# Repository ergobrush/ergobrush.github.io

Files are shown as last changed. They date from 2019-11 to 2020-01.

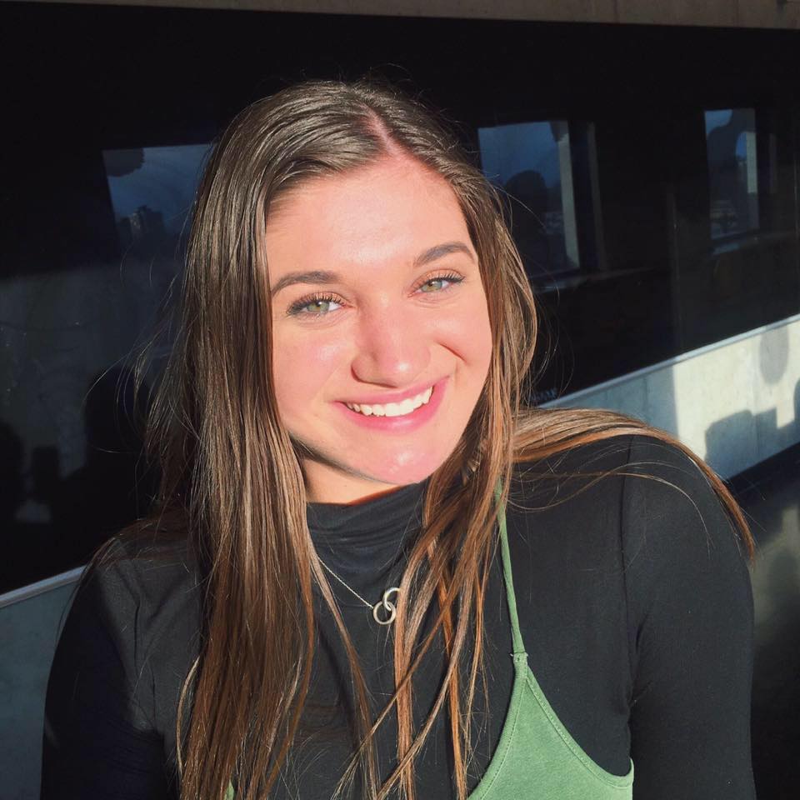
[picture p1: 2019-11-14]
img/kate.jpg

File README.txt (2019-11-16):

Ergobrush
=========

Description:
Ergobrush is a hand held gimbal-style device that provides three axis of rotation. This allows the user to achieve all desired angles to fully brush their teeth without necessitating the movement of their hand. Our device is designed to provide independence to individuals with hand mobility constraints when brushing their teeth.

Team Members:
Anbo Xu
Andre Frenette
George Abou-Hamad
Kate Ford
Lucas Hubert

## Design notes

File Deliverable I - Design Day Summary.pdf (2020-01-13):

Project Deliverable I: Design Day Pitch and Final Prototype Evaluation GNG 2101 – Intro. to Product Dev. and Mgmt. for Engineers Faculty of Engineering – University of Ottawa

Date: November 28th 2019
Group number: Group 10
Group members: Andre Fernette, Anbo Xu, George Abou-Hamad, Kate Ford, Lucas Hubert

Introduction
In preparation for this long awaited and important day, our group got together to brainstorm ideas on how we could best present our final prototype. Together, we prepared a 2 minute pitch that we would deliver to our judges, peers, professors, potential users, customers and anyone who else who may be interested in our product. We also prepared ourselves to answer any potential questions that may be asked pertaining to our design. This two minute pitch contained the information regarding the “So What?”, “Who Cares?” and “Why us?” aspects of our device and ended in a live demonstration of our fully functional prototype.

We also provided our visitors with various visuals to refer to during our presentation. This included a presentation board, our first prototype model, our final prototype and two display screens as shown below.

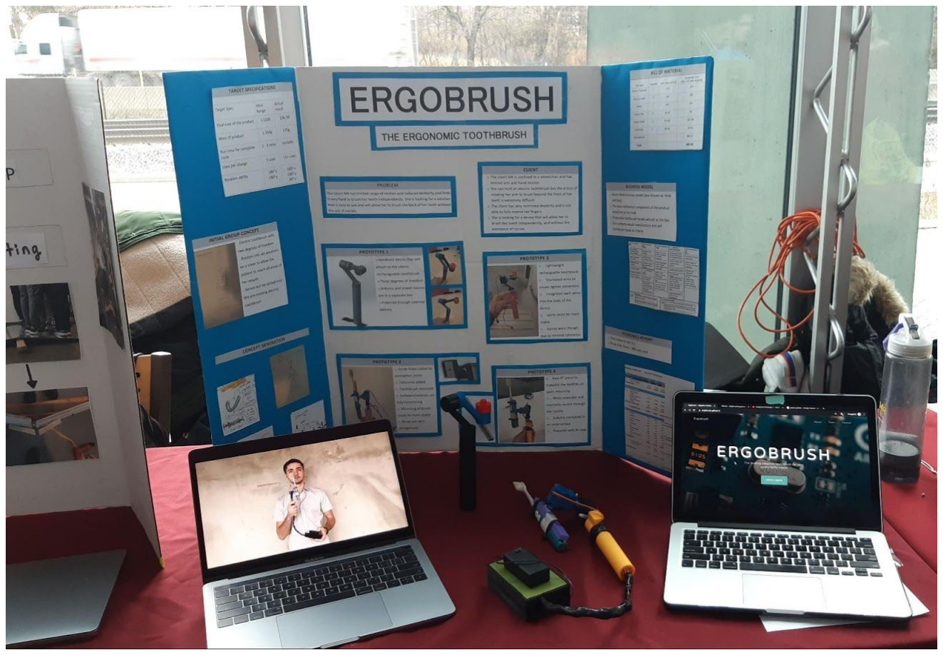
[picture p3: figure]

Design Day Presentation Material breakdown:

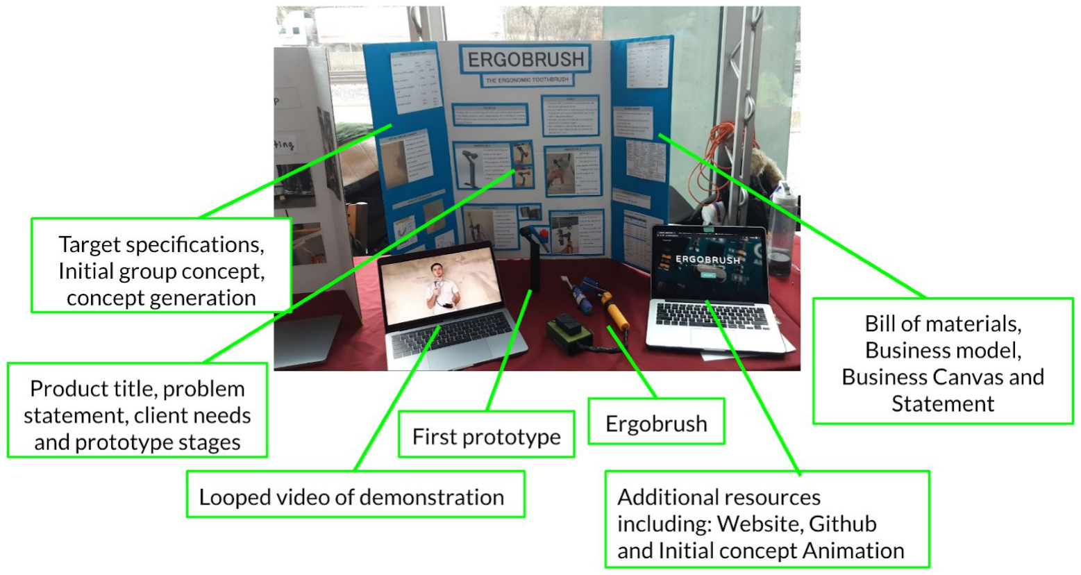
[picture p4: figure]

We used a presentation board to illustrate the design process we had followed throughout the semester. On the left we have the target specifications, initial group concept and concept generation. In the middle we have our product name, problem statement, client needs and animations and pictures of our various prototypes we designed. Finally, on the right we included the bill of materials, our business model, business canvas and a 3 year economics statement.

On the bottom left screen we have a video of one of our team members demonstrating the device in use. We uploaded this video to youtube and looped it throughout the day to provide visitors a quick glimpse of how the device functions.

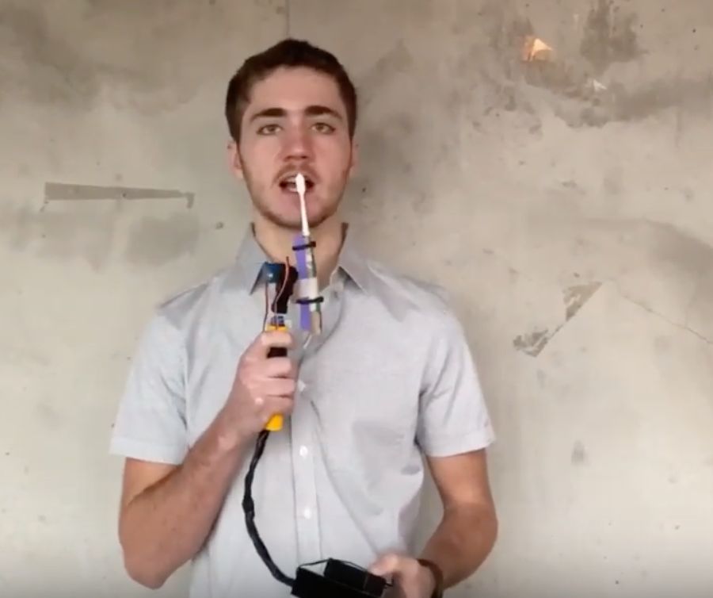
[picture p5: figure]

https://youtu.be/_NtiQT6FsqM

On the bottom right screen we provided additional resources that we believed would be of use to our judges and visitors. This included a link to our website and github page which was used to view the code implemented. We also demonstrated a short animation of our initial concept we rendered in cinema 4D.

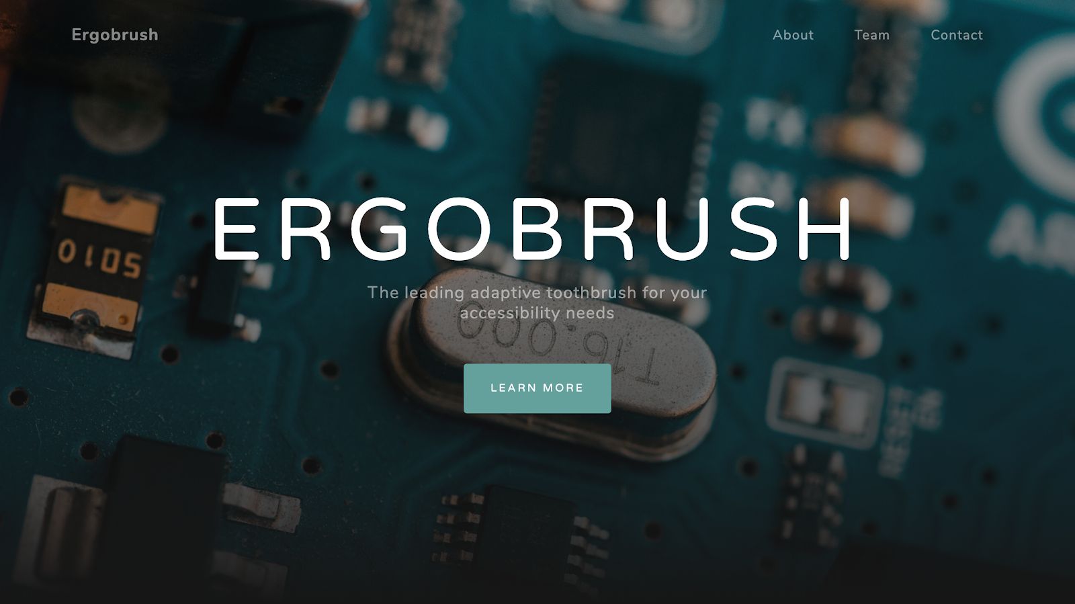
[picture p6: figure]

https://ergobrush.github.io/

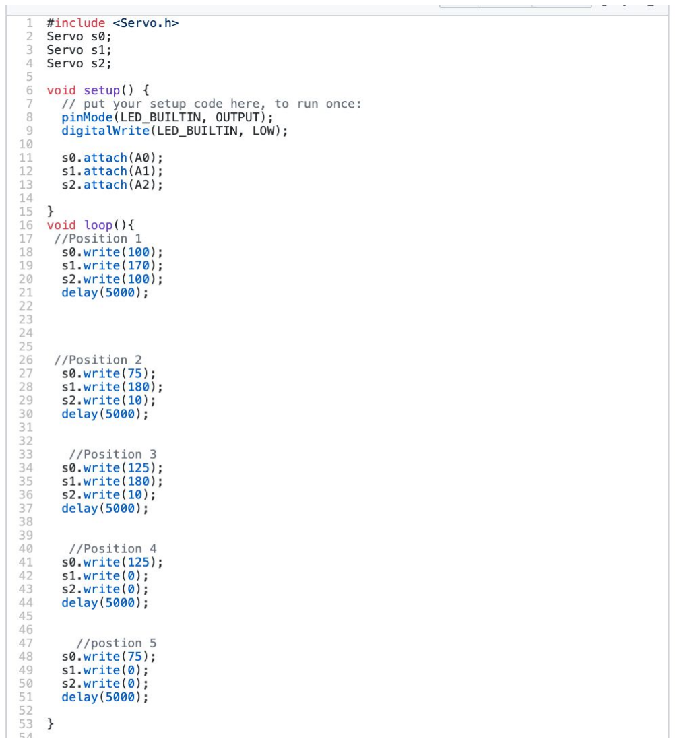
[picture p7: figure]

https://github.com/ergobrush/ergobrush.github.io

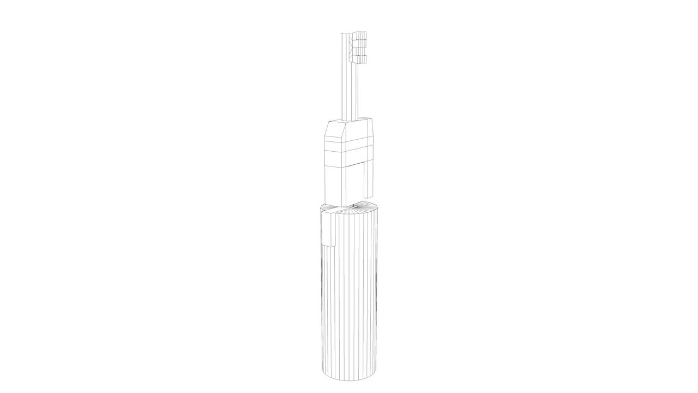
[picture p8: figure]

https://www.youtube.com/watch?v=FklP977IuZg

Two-line summary:
Ergobrush is a hand-held assistive toothbrush that allows the user to brush their teeth without requiring the need to move their hand. By offering three axis of rotation, Ergobrush effortlessly emulates a natural brushing experience through the execution of timed positioning sequences.

Conclusion
Although we did not place in the competition, we had a great time presenting the product of our hard work. We received many compliments on our design as well as good feedback and potential adjustments to better improve our product moving forward. Most importantly, as a team we believe we gained a lot in terms of technical and team working skills. From communication to group management, we will carry and apply what we’ve learned together in our future experiences to come.

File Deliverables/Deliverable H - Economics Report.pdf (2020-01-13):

Project Deliverable H: Economics Report and 1 Minute Video Pitch GNG 2101 – Intro. to Product Dev. and Mgmt. for Engineers Faculty of Engineering – University of Ottawa

Date: November 14th 2019
Group number: Group 10
Group members: Andre Fernette, Anbo Xu, George Abou-Hamad, Kate Ford, Lucas Hubert

Introduction

In this deliverable we will develop a forecasted income statement for our company based on the business model we previously developed for our team’s product. To achieve this, we will classify the various costs associated with our business, develop a 3-year income statement, determine our break-even point using an NPV analysis and finally provide arguments justifying the assumptions made in developing our economics report.

Finally, we will create a short video introducing our brand, explaining the problem we are solving and discuss the competitive advantages our solution has to offer. Our video pitch will be directed towards potential clients and investors.

H.1 Economics report:

### 1. Include a list of: variable, fixed, direct and indirect costs associated with your

business, based on the manufacturing and sale of your product. Make sure that you distinguish between price and cost and realize that prototyping and higher-volume manufacturing costs will probably differ.
Cost | Classification
Material | Variable, Direct Cost
Production | Variable, Direct Cost
Salary | Fixed, Indirect Cost
Depreciation | Variable, Direct Cost
Overhead | Fixed, Indirect Cost
Electricity | Variable, Indirect Cost

Rent | Fixed, Direct Cost
Financing | Variable, Indirect Cost
Cost of Labour | $18/hour
Material Costs | Injection molding - 1kg at $1/kg Servos - 3 servos at $10/servo Arduino - 1 arduino uno at $10/arduino Arduino Shield - 1 Shield at $5/shield External Battery - 1 battery at $5/battery
Total Material Costs | $51

### 2. Develop a 3-year income statement, which includes: sales revenue and costs of

goods sold for each year, gross profit, operating expenses and operating income (no need to include interest and taxes).

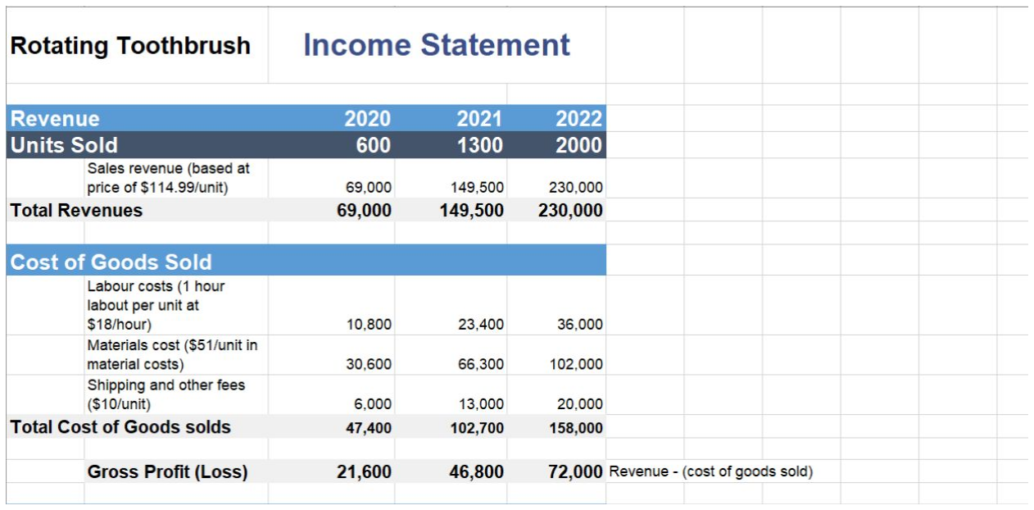
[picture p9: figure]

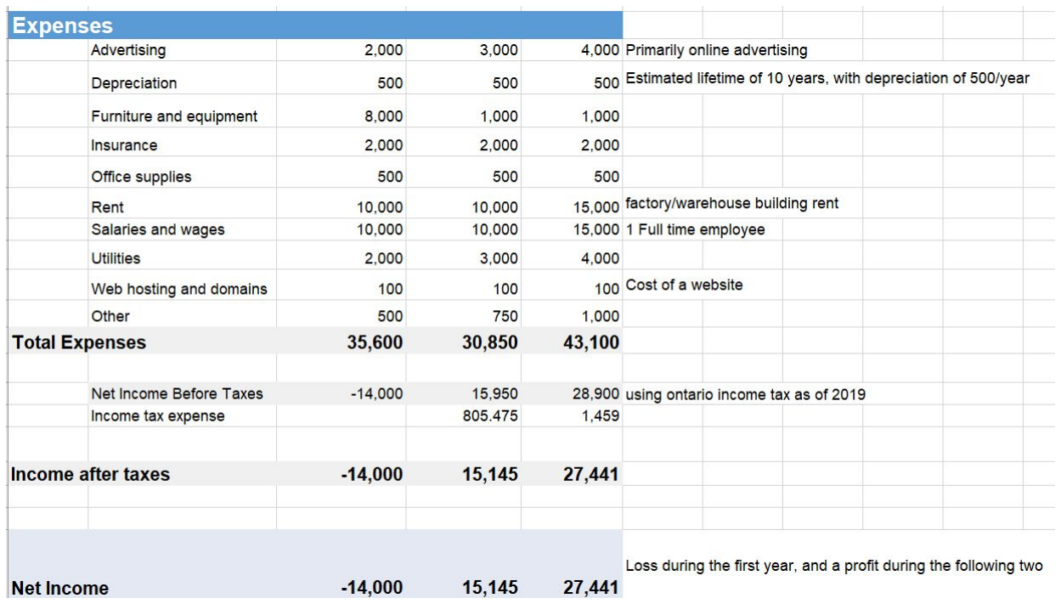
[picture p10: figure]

### 3. Using a NPV analysis, determine the break-even point (it is highly unlikely that your

operating income will be positive in the first year because of fixed costs).

Break-Even Point = (Fixed Cost) / (Sales Price Per Unit - Variable Cost Per Unit) Break-Even Point = (35,600) / (115 - 79)
Break-Even Point = 988.8 units
Break-Even Point = 989 units

### 4. Describe and justify all assumptions that you have made in developing your

economics report.

Assumption | Justification
Supply/Dema nd analysis | According to Statistics Canada, there are 60,000 people with cerebral palsy living in Canada. Assuming 1% of those people would benefit and purchase our product that is 600 people. This is where the number of unit sales in the first year originated from. Since our product is not targeted solely to people with cerebral palsy, the 600 units will consist of other various demographics sharing similar issues.
Tax | As our company will operate locally, the income tax was calculated using the

| current Ontario income tax stating that $10,582 - $43,902 has a tax of 5.05%.
Unit pricing stability | It is unlikely that the prices of our units will fluctuate as the raw materials used are relatively inexpensive and abundant in the market. As our wages are set significantly above the average minimum wage in Canada, it is also unlikely that we would have to wages.
Product market | The market for this product exists as it has been set with a price of $115. Upon researching our market, we noticed many other less advanced options being priced at around $100-$150. Since our targeted client demographic are individuals with disabilities, the price will most likely be covered by insurance, preventing any potential difficulties accessing our products due to financial Reasons. For those reasons we believe our product is priced fairly and competitively given its functionality.
Research and development | The product will remain current and will not require updates within the next 3 years. By keeping overall costs low, we are able to maximize our profits while also collecting data from our users. Once our company has more leeway after the first 3 years, we will analyze the feedback and if need be, design a second version of our product.

H.2 1-minute video pitch. Create a video, approximately 1 minute in length. https://makerepo.com/GeorgeA/ergobrush-the-leading-adaptive-toothbrush

Conclusion

Upon classifying our various costs associated with our business, we were able to complete our income statement. For the first three years of operation, our net income was calculated to be -$14,000, $15,145 and $27,441 respectively. We then conducted a NPV analysis, determining a break-even point of 989 units. Concluding our economics report, we analyzed and justified the various assumptions we had made in developing our economics report.

Preceding the report, we created a short video pitch with the purpose of shedding light on our problem statement while also displaying the effectiveness of our proposed solution. We decided on naming our product Ergobrush as we believe it properly encapsulates the ergonomic design and function of our device. We also created a product website which will be used to provide further information to potential clients and investors.

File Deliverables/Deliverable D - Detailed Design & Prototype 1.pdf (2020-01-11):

Project Deliverable D: Detailed Design and Prototype 1 GNG 2101 – Intro. to Product Dev. and Mgmt. for Engineers Faculty of Engineering – University of Ottawa

Date : October 3rd 2019
Group number: Group 10
Group members: Andre Fernette, Anbo Xu, George Abou-Hamad, Kate Ford, Lucas Hubert

Introduction:

MK is constrained to a wheelchair and has no hand control, as well as limited arm range. She has difficulty brushing her teeth with no assistance. Although she can hold an electric toothbrush, the action of rotating the toothbrush to reach beyond the front tooth surface is a challenge. Having a device that can assist in the rotation of the electric toothbrush will allow her to live more independently. This rotational toothbrush must use off-the-shelf brush heads for sanitary reasons. Ideally, this toothbrush is rechargeable, but a secure power wire is acceptable.

Since being assigned the task to solve MK’s problem, our team has worked long and hard in formulating a viable solution for our client. Following the directions in deliverable C, we were able to clarify the core functionalities our solution was to have. We then pooled together our ideas, further analyzing them using concepts learned in class such as the decision matrix. Using the results obtained from these matrices, we developed a group concept that integrated key components found in the most promising solutions. Finally, we developed a project plan, conducted a feasibility study and created a bill of materials and parts to verify the viability of our proposal.

Our current objective is to design details for our concept and to build our first prototype. This will serve as a means to test the product’s most critical functionality and target specifications. We will then use the prototype to interact with our client and obtain valuable feedback on our next meeting.

GNG 2101 – Intro. to Product Dev. and Mgmt. for Engineers

### 1. Summarize the client feedback that you received during your second meeting

for your conceptual design and clearly state what needs to be changed or improved in your design.

Upon meeting with our client for a second time, we were able to present our group concept we had at the time. This meeting was extremely informative as we were given feedback regarding the feasibility aspects of our concept.

At the time of our second meeting, our group concept was a customized standard electric toothbrush that would have two degrees of freedom. While being operated, the upper portion of the toothbrush would be able to spin and tilt, allowing the user to reach an increased amount of surface area without necessitating hand motion. We created the sketches below as an accurate representation of our product concept at the time.

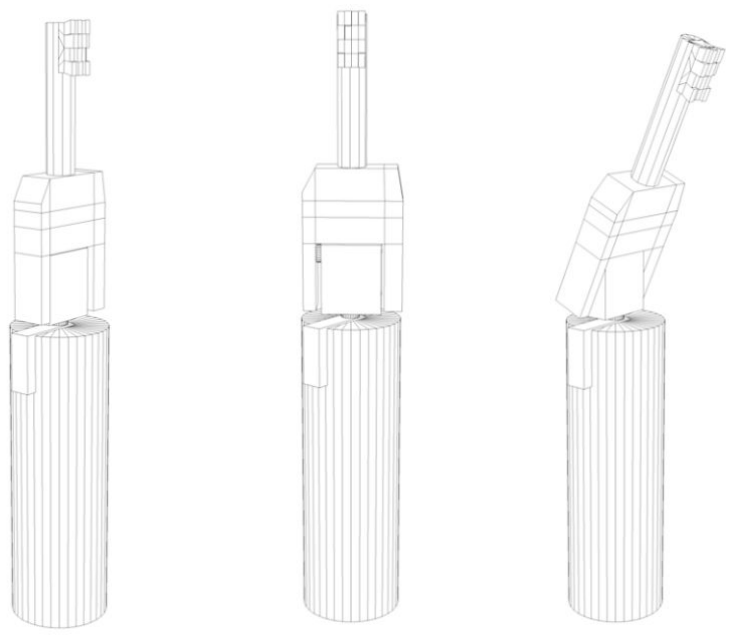
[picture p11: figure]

However innovative the concept was, the client did express some concerns with its design. The proposed device needed a continuous flow of energy from a power outlet in order to power the various electrical components while being operated. Since our product will be in contact with water, we were advised that the device must be unplugged while in use to ensure the safety of the user. To improve this design characteristic, we decided to modify our concept to contain an external battery component that the device would draw energy from and that could be recharged when not in use. This would also be of great use to house the wires, keeping them away from the chairs vicinity and to prevent potential damages to the system from contact with water.

Our client also expressed concerns with regard to the weight of our design. As the weight of our concept included a standard electric toothbrush as well as an arduino, two servos, wiring and a longer 3D printed case, the weight of the device would not meet our clients needs. In order to have a viable concept, our target specification for weight must not significantly exceed the weight of the current toothbrush she uses. We realized that an alternative concept was needed, ideally one that did not require all the components to be affixed to the toothbrush itself.

Another concern from our client was the complexity of our design. Given the course’s restricted timeline and the limited time allocated to build the final prototype, the client recommended that we keep our design as simple as possible to make sure that we are able to complete it on time. In order to achieve that, we planned on developing a simpler design to ensure that we could complete each design process milestone leading to our final prototype on time. Also, crucial steps such as software testing will have to be completed well ahead of design day to ensure that it is functioning properly and according to our target specifications.

Given the feedback provided by our client and project manager, we decided to make important changes to our design. We realized our design needed to be first and foremost safe, light weight, cost effective and simple in nature. In order to meet these specifications, the device had to work independently to the toothbrush. By choosing a design concept as such, we would dramatically decrease the cost of our product as we would simply use our clients current toothbrush. This would also maintain the integrity of the electric toothbrush and prevent any safety concerns that could arise by directly altering its components.

### 2. Develop an updated and detailed design of your concept, based on your client

meeting, which includes: Visual representations of the overall concept, as well as each subsystem. Clearly define how each subsystem is linked to other subsystems (including fasteners and electrical wires).

Through a collective effort, we were able to conceptualize a design that met our product specifications. Our new design is a hand held device that would attach to our clients toothbrush and perform various movements. The design was inspired by a phone gimbal, a hand held device that is meant to stabilize a phone while taking video. A sketch of our new design is provided below.

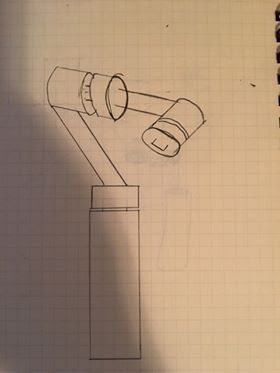
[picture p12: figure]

An updated, visual design of our overall concept created in Solidworks is provided below.

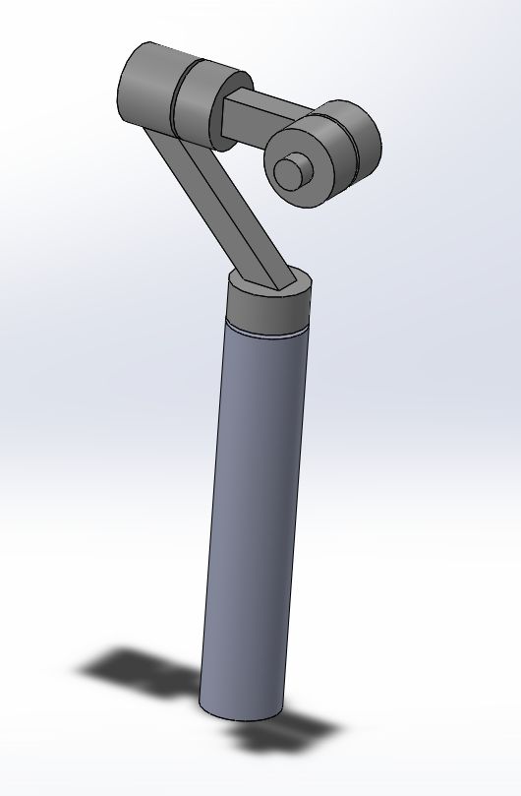
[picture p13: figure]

Subsystems at a glance: Handle, servos, wires, different pieces on the gimbal.

Our concept incorporates a simple design that would be comprised of a handle, various pivots through the use of servos and a fastener that would latch onto the toothbrush, providing the motions needed for the user to brush their teeth.

In order to guarantee full product functionality to our client, certain preconditions must be met during the external boundary phase. To begin, the toothbrush intended to be used must be picked up, wrinsed, have toothpaste applied to the bristles and the toothbrush must be attached to the device. Additionally, both the toothbrush and device must be charged to ensure proper functioning. The device must also be handed to our client and turned on as she is incapable to do so alone.

The system will now perform as advertised until our client has completely brushed all of their teeth. While holding onto the device, the toothbrush will have a timed sequence of various positions, ultimately providing the user with an ample amount of time to thoroughly brush each section of their teeth. This will be achieved using the dynamic subsystems that compose our device. These include the handle, joints/servos, battery, arduino and wires.

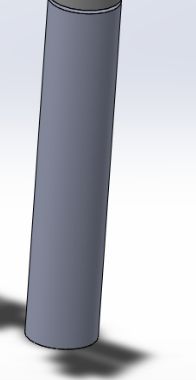
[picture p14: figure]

Handle

The handles function will serve as a replacement to the original toothbrushes handle.It will be of similar diameter to an electric toothbrush and easy to grip. Padding will be added to ensure comfort while operating device.

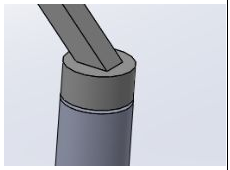
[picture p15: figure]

First Joint

The first Joint allows the device to rotate on
the xy plane. The servo will be mounted in
the handle and the second piece will be mounted onto the splines of the servo. The wires that lead to the following two servos will be routed through this joint.

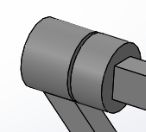
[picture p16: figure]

Second Joint | The second joint allows for the joint to have freedom of rotation on the xz plane. The joint will be assembled in the same manner as the first joint. The wires for the third servo will route through this joint in a manner that will not interfere will other motions.

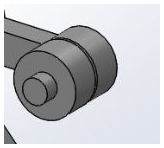
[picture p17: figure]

Third Joint | The third joint allows for freedom of movement on the xy plane. This joint will also be assembled in the same manner as 1 and 2. The third servo will allow the toothbrush to be angled away from and toward the client.
Wires | The wires are not illustrated in the visual design as they will be hidden from plain sight. They will serve as a means to connect all electrical components in order to ensure proper functioning of the device.

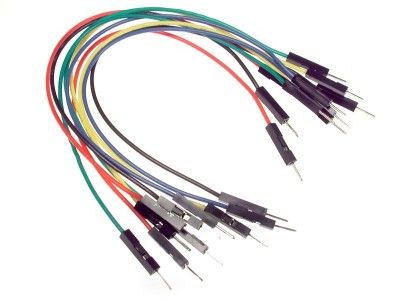
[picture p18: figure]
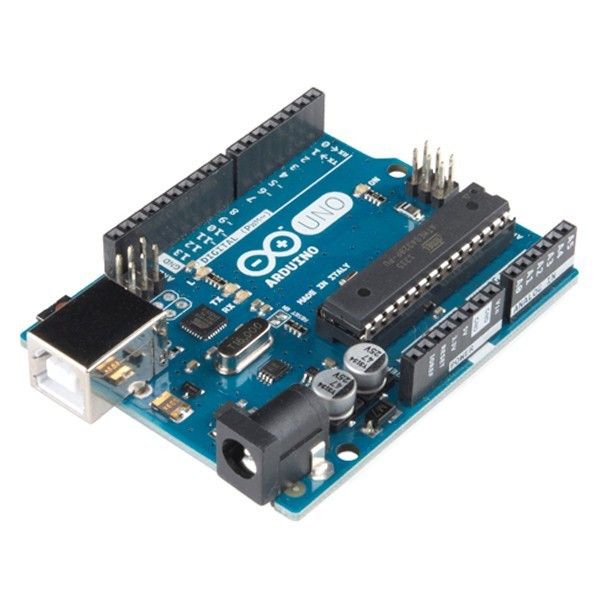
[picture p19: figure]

Arduino | The Arduino microcontroller is programmed to control the rotations of the servos. After a certain amount of time, the microcontroller will adjust the toothbrush to let the client brush other sides of her teeth. After a full cycle, the microcontroller will send signals to reorient every joint to its initial position and then automatically turn itself off.

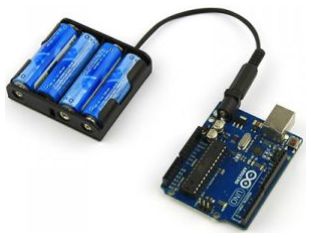
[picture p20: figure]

Battery

The battery pack we have will supply power to the arduino. We are using an external battery pack so it does not have to be plugged into a standard wall outlet. Plugging the Arduino into the wall would present an obvious safety hazard as the task of brushing your teeth involves water and having wires and power running around the client is not ideal.

Once a cycle is completed, the device will turn itself off. When the user has fully brushed their teeth, the aide will unmount the toothbrush and rinse it off. The batteries of the device and toothbrush will then need to be charged for the next use. A function will be implemented that resets the devices positioning prior to turning off.

### 3. Define your most critical product assumptions and create your first product

prototype, which will be used to test those assumptions.

In an ideal scenario, we would be able to fully test our product specifications using an unlimited amount of resources. Unfortunately, as we are advised to follow a strict budget, multiple assumptions must be made prior to developing our product. Notably, the components that tend to be the most expensive are the ones that utilize energy and perform work. These include components such as the servos, arduino and batteries.

The servos are expected to perform enough work to rotate a designated area of the device, we must assume that they will perform as intended. The device must also accomplish a sufficient amount of degrees of freedom in order to work as advertised.

To add, we must assume that our product in its entirety will share a similar weight to a standard electric toothbrush. Having it be too heavy will hinder our clients ability in utilizing it, rendering the device useless. Also, if certain areas are of too much weight, this will once again prevent our servos from completing their rotations and may potentially damage the equipment.

Taking these product assumptions into consideration, we are ready to create our first product prototype which will be used to test our assumptions.

### 4. Document your prototype using as many sketches/diagrams/pictures as

required and explain the purpose and function of your prototype.

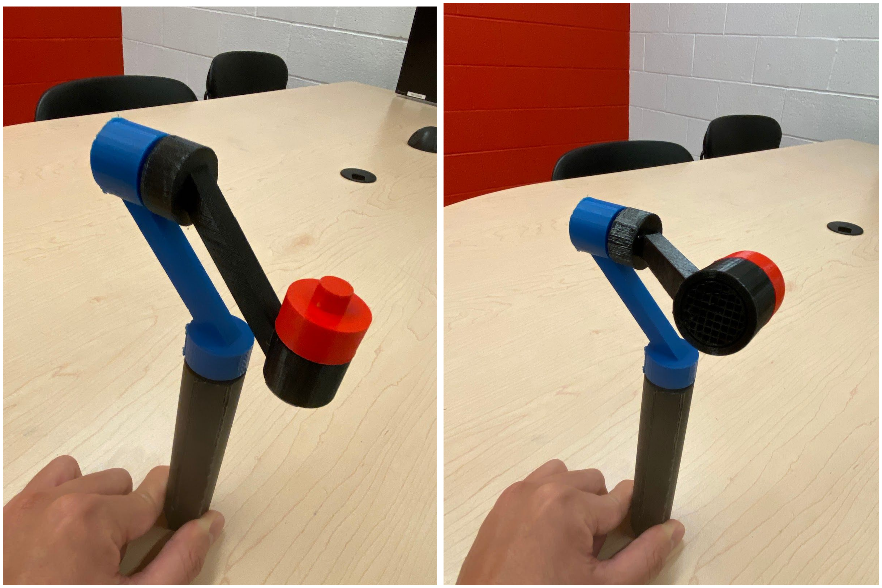
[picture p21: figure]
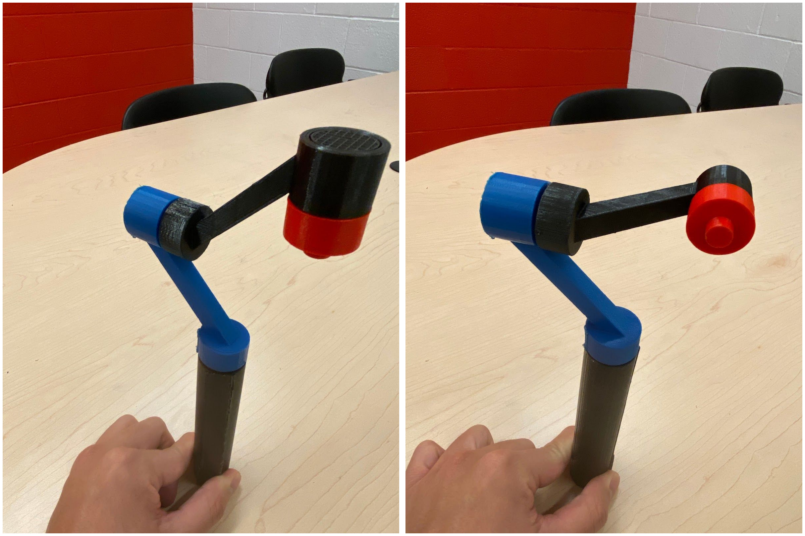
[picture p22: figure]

We created a low fidelity prototype to quickly test our idea with no cost to the team. Each of the four fidelity factors have been addressed within the initial prototype.

Functional Fidelity: This is a moderately functioning prototype. Since all the pieces were printed independently they are able to be assembled and manipulated to simulate the movement that will be happening with the servos. There is no software within the prototype so all of the movement is done manually by the user.

Visual Fidelity: This prototype is not an accurate representation of what the finished product would look like visually. The structure and shape of the product will be similar but the colors and coordination of the product will be improved.

Content Fidelity: Currently there are no placeholders for the servos what will be added to the final product. A servo will be placed at each of the three joints where the parts meet.

Depth and Breadth: The overall completeness is very surface level. From now until the final prototype there will be mechanical aspects added, a battery system will be implemented, servos will be incorporated, and a clasp to hold the toothbrush will be added as well.

The main purpose of prototype 1 was communication, specifically the validation of our ideas. Creating the prototype as a 3D printed model that we can manipulate allowed us to confirm that gimbal style will be functional and allow the client to reach all the areas of her mouth with ease. The model also let us get a feel for the weight of the product. Since the client is not able to hold something that is too heavy or off balance we are able to keep the weight in mind when building on the design.

### 5. Carry out prototype testing, analyze and evaluate performance compared to the

target specifications developed in Project Deliverable B and document all your testing results. Present your testing in an organized, tabular format that shows expected versus actual results.

As our concept was recently developed due to the feedback provided in our
second client meeting, we decided to follow the preliminary steps completed for
our older designs found in Deliverable C prior to creating our first prototype. We created a decision matrix for our gimbal design to identify, analyze, and rate each design criteria in relation to the selection criteria. The values for our matrix are set to 1 being not ideal and 5 being ideal.
Selection Criteria | Gimbal Design
Ease of Use | 5
Size & Weight | 4
# of Adjustments per cycle | 5

Safety | 4
Durability | 4
Cost Estimate | 5
Is it Realistic | 4
Total | 20

As the purpose of creating a prototype is to reduce uncertainty, we wanted to create one that would provide insight on our final product. The purpose of our prototype was to test basic functionalities of our device. Notably, we wanted a physical model that would shed light on the dimensions, weight and ergonomics of the device. We decided the optimal way in testing our product specifications was to 3D print our design as it could demonstrate the basic motions, shape and weight of our final device.

For our product size, we decided it would be best if the handle component to emulate the dimensions of a standard electric toothbrush, being 11 x 5 x 24.1 cm. We also wanted to demonstrate that the weight of our final product was expected to be relatively light. Thus, we made sure to keep the handle hollow and made sure that all components did not weigh more than an electric toothbrush ~331g. By using a simple design made of plastic for our first prototype, we were able to conceptualize where the servos would be inserted and how they would behave with respect to motion.

The portion of our functional decomposition that could be tested using our prototype were the steps included within our system boundaries. Once the toothbrush is on, attached to the extremity and given to the user, we would then illustrate the different positions the toothbrush could achieve without the movement of the users hand.

The assembly of the prototype was relatively easy, though not completely stable. It did suffice to give the user a general idea as to how the form of the final concept would be like. We then provided our prototype to our friends to receive user feedback. Overall the feedback was positive. The metrics of what was tested, expected results and actual results are provided in the table below.

Test | Expected | Actual
Length when standing up with the red component | 20cm | 23cm

shown in the picture facing down | Size of the apparatus is similar to an electric toothbrush. | Size of handle and feel were accurate. Upper components were slightly big and could be a problem when oriented too close to the users face.
Weight | 200g Product is lightweight, similar to that of an electric toothbrush. | 164g Weight was very similar to an electric toothbrush. Though the prototype did not contain any of the components we plan on adding, the fact that it was significantly lighter provides good prospects of a light final product, for when we do decide to add them.
Ergonomics | Prototype demonstrates efficiency and is easy to use. Provides a comfortable and natural feeling, similar to holding a toothbrush. | Emulated with significant accuracy the feel and design of an electric toothbrush. Upper components were slightly big and could be a problem when oriented too close to the users face.

Overall the feedback was positive. Some confusion arose as to how the device was to behave when on. Recommendations on timed intervals as opposed to buttons for the various different motions were asked. To get accurate feedback regarding our client, when we informed our testers on the physical constraints of our client, the majority of our testers preferred a timed design.

Testing our prototype was an inexpensive and time saving process that provided important insight on the direction we should follow from here on out.

### 6. Outline what your team intends to present to your client(s) and what

information you would like to gather at your next client meeting.

Much has changed since our second client meeting. As a team, we have decided upon a completely different product design due to the concerns and criticism provided by our client and project manager. Given the fact that our next client meeting is scheduled in roughly three weeks, we plan on taking advantage of this opportunity to further refine our current product design prior to the meeting. Based on our current expected milestones, we plan on providing our client with a high fidelity prototype by October 23rd. This comprehensive prototype will implement many of the attributes our final product will contain and be of great use for rigorous testing. This will also provide our client with a better sense of the solution, the expected features and functionalities of the final product, the option to test our prototype and ultimately give insight on preferences they may have, allowing us to further refine and finalize decisions pertaining to our final product.

By inquiring on our clients personal preferences, taking into account their exact movement capabilities, we are given the opportunity to further meet their needs by altering the specific timing and positioning preferences they may have with respect to the motion of the device. We will achieve this by modifying the code affecting the functionality of our servos. This is now a possibility due to our newly acquired knowledge upon completing our most recent laboratory. During this lab, we utilized the Arduino IDE Software platform to write control logic commands used to create inputs and outputs connected to an Arduino Uno microcontroller.

Conclusion:

This week, we decided to develop a completely new design influenced by the feedback provided during our second client meeting. We then created our first prototype using the designed details of our concept through the use of sketches and 3D models. We tested our products most critical functionalities and target specifications with friends to get informative criticism on our product design. Finally, we established what we plan on presenting in our next client meeting as well as inquire on preferences that will be used to finalize our product.

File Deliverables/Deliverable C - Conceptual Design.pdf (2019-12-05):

## GNG 2101 – Intro. to Product Dev. and Mgmt. for Engineers

Project Deliverable C-1: Conceptual Design
Faculty of Engineering – University of Ottawa

Date : September 26th 2019
Group number: Group 10
Submitted by: Andre Frenette, Anbo Xu, George Abou-Hamad, Kate Ford, Lucas Hubert

Introduction:

The objective of this deliverable is to develop a conceptual design for our product as well as to create a plan for completing multiple prototypes in time for Design Day. In order to verify the viability of our proposed concepts, we conducted a feasibility study and created a bill of materials and parts (BOM).

### 1. Based on customer needs, clarify core functionality by breaking down required

product functions (functional decomposition) into smaller basic sub-functions, identifying external sub-system boundaries.

Functional Decomposition:

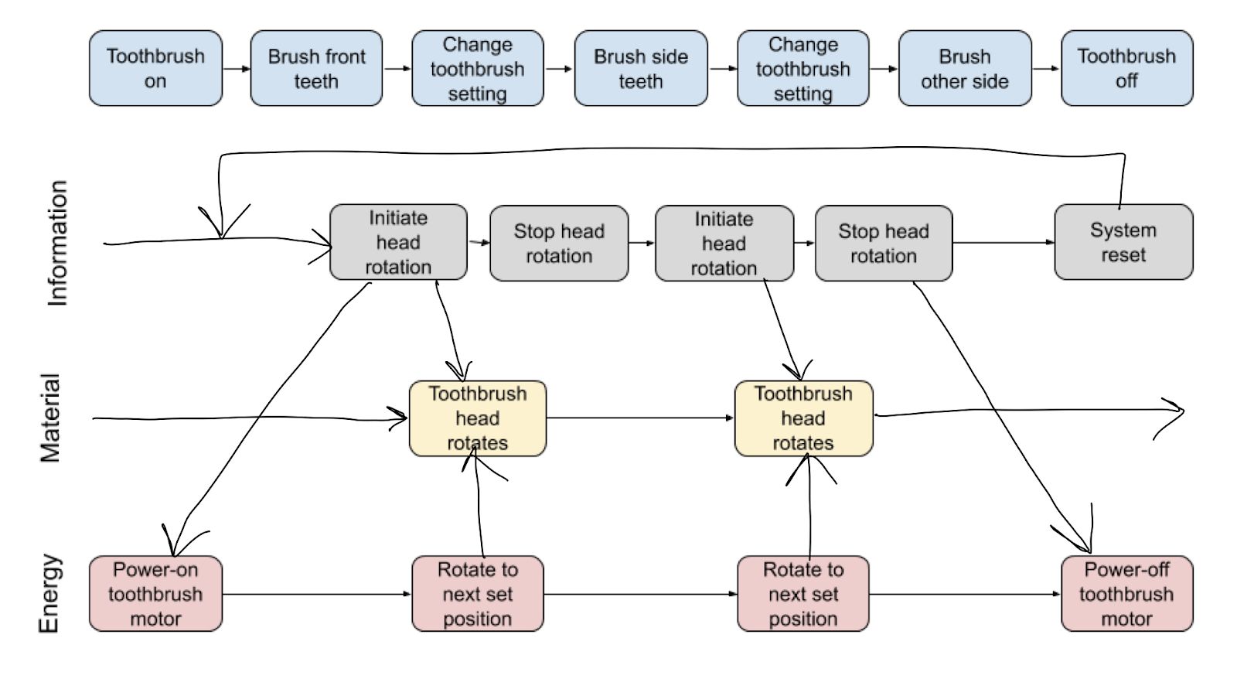
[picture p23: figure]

### 2. Provide a minimum of 3 product concepts per team member (clearly identify

each concept’s creator).

Lucas’ concepts:

1) A device that attaches around the head while the toothbrush is inserted in the mouth. The functionality of the device will rely on the user's head movement. As our client would prefer a solution that aides, but does not replace her participation in brushing her teeth, a design such as this could incorporate our clients strengths while minimizing the necessity of their weaknesses. Potential cons for this solution would be the complexity in the setup stage, the size of the apparatus as well as its increased weight.

Pros: Relies on the client’s strengths to operate the toothbrush. Requires minimal hand movement.

Cons: It would be hard to set up, and take up a lot of space. Also, depending on the materials used, weight could be an issue.

2) A longer toothbrush that has a better reach than a standard one could be a viable solution. By utilizing such a device, reaching the teeth located on the side and back regions of the mouth could be achieved without moving the users hand. Adding length to the toothbrush would inevitably increase the weight of the device which could be an issue. An increased difficulty in handling the toothbrush may also arise given the change in the devices overall form.

Pros: It would make it easier to reach the sides and back of the mouth cavities without having to move hands. This would allow the client to only rely on head movement, one of her strengths.

Cons: Weight could be an issue. Also, it could be hard to grab or use given the client’s restricted hand motion.

3) Device to wrap around hand to make grabbing the toothbrush. Adding optional extra length to allow to use head movement to reach sides and back of mouth cavity. A device that would assist the user by wrapping around their hand could be of potential use to our client. It would be an inexpensive tool in providing extra grip to the toothbrush while it is being operated. The attachment and removal procedure as well as the additional weight on the users hand could be an issue.

Pros: Easy to use, it would provide extra grip to help the client grab and use the toothbrush.

Cons: Again, weight could be an issue, as well as set up. If it is too heavy, it could be problematic given the client’s limited hand strength.

George’s concepts:

1) A 3D printed piece that would attach between the base of the electrical toothbrush and the removable head. This piece would be comprised of 2-3 compartments, one being a cog. The cog would have around 4 protrusions that would be used as a gripping tool to turn the head piece. It would be designed to turn clockwise in 90 degree increments with the use of applied force. For instance, once the user has completed the task of brushing their front teeth, they would then bite on the cog and twist using both their arm and head. Upon completion, the bristles would be facing 90 degrees away from its initial position and the user may now begin brushing the surface of their bottom teeth.

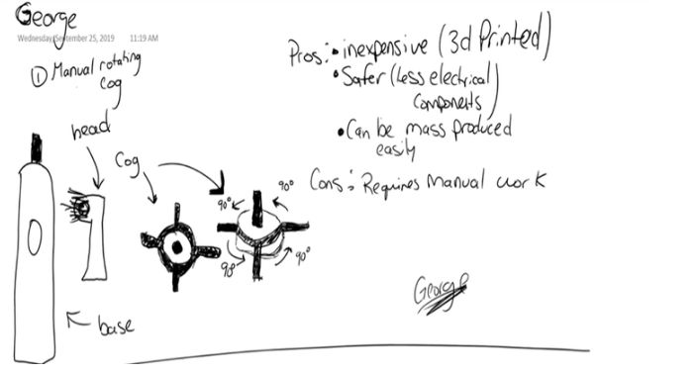
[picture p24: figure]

2) An attachable handle that would rotate via a control. The Handle would attach to the chairs surface or bathroom sink and grip the toothbrush when being operated. An easy to use button that would require minimal pressure would be in the users reach. When the button is pressed, the rotational mechanism would be

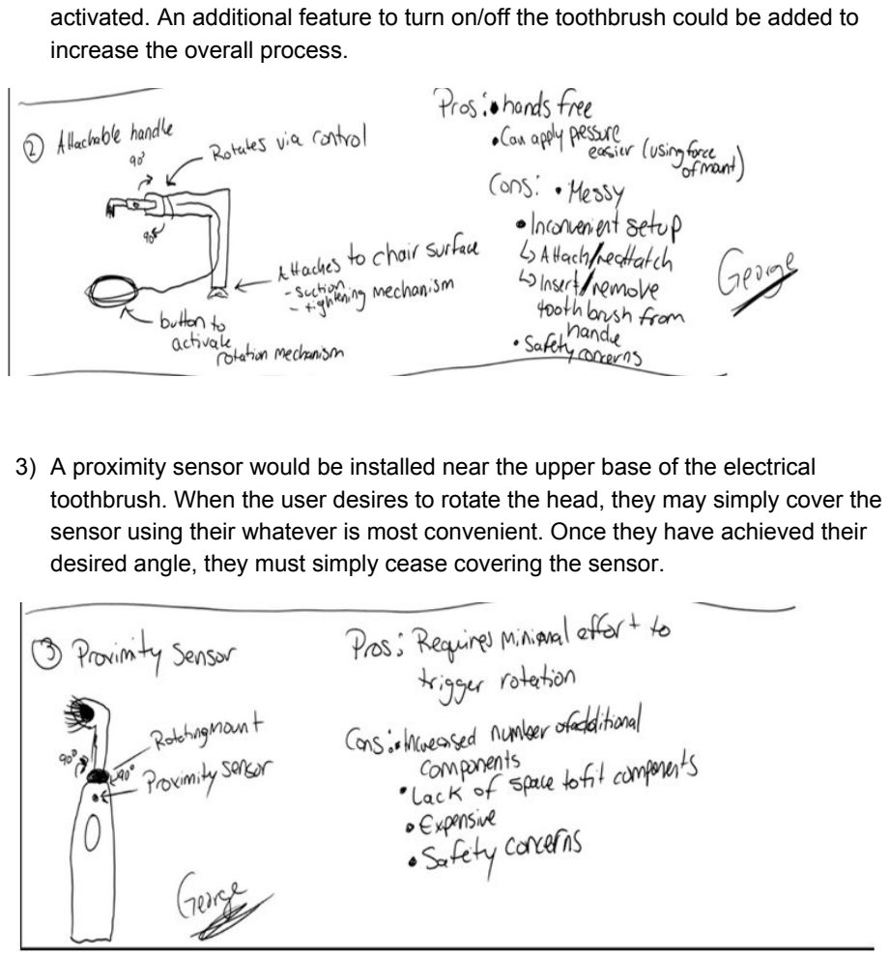
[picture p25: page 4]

activated. An additional feature to turn on/off the toothbrush could be added to increase the overall process.

3) A proximity sensor would be installed near the upper base of the electrical toothbrush. When the user desires to rotate the head, they may simply cover the sensor using their whatever is most convenient. Once they have achieved their desired angle, they must simply cease covering the sensor.

Anbo’s Concepts:

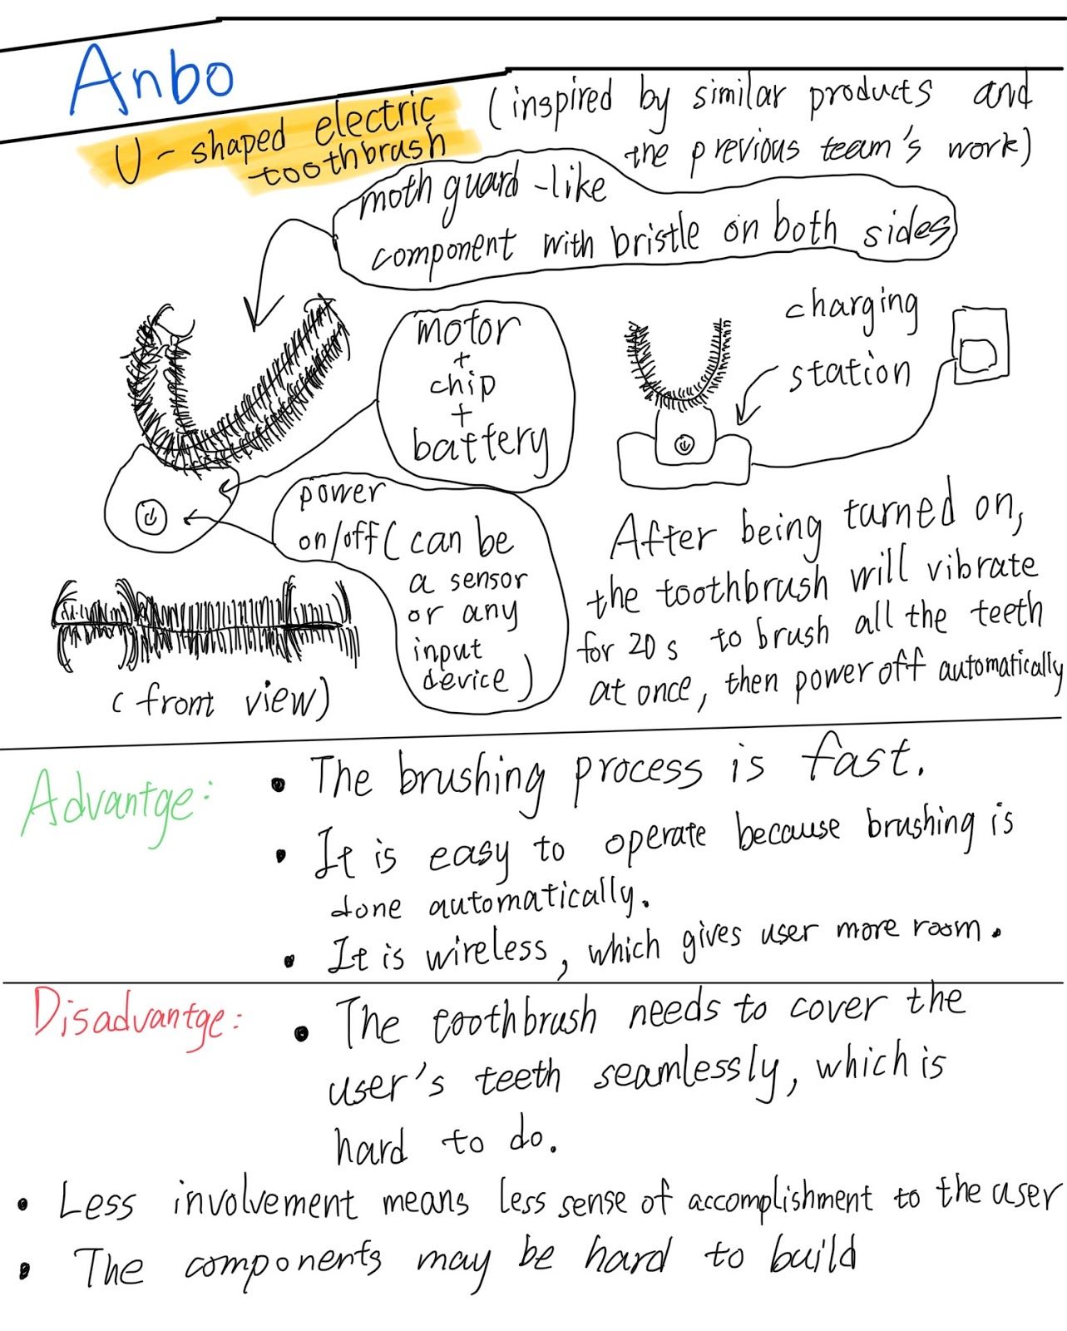
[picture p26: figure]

Kate’s Concepts:


Andre’s Concepts:


### 3. Analyze and evaluate all concepts provided by each team member based on

the target specifications of Project Deliverable B. Use simple calculations and/or simulations to make decisions. Justify the process and methods used for analysis and evaluation.

Upon reviewing Mana’s comments for Deliverable B, we have refined our metrics and target specifications for our solution. In order to best analyze and evaluate all concepts provided by each team member, we created a decision matrix. By doing so, we are able to systematically identify, analyze, and rate each design criteria in relation to the selection criteria. The values for our matrix are set to 1 being not ideal and 5 being ideal.

Lucas’ Concepts
Selection Criteria | Concept 1 | Concept 2 | Concept 3
Ease of Use | 3 | 3 | 4
Size & Weight | 1 | 2 | 2
# of Adjustments per cycle | 2 | 4 | 1

Safety | 3 | 4 | 4
Durability | 4 | 3 | 4
Cost Estimate | 4 | 4 | 3
Is it Realistic | 3 | 3 | 3
Total | 20 | 23 | 21

George’s Concepts
Selection Criteria | Concept 1 | Concept 2 | Concept 3
Ease of Use | 3 | 4 | 2
Size & Weight | 5 | 1 | 1
# of Adjustments per cycle | 3 | 2 | 3

Safety | 3 | 2 | 2
Durability | 3 | 2 | 2
Cost Estimate | 5 | 2 | 2
Is it Realistic | 4 | 3 | 2
Total | 26 | 16 | 14

Anbo’s Concepts
Selection Criteria | Concept 1 | Concept 2 | Concept 3
Ease of Use | 4 | 3 | 3
Size & Weight | 3.5 | 3 | 3
# of Adjustments per cycle | 4 | 3 | 3

Safety | 3 | 3 | 3
Durability | 3 | 3 | 3
Cost Estimate | 2.5 | 3.5 | 4
Is it Realistic | 4 | 3.5 | 3
Total | 24 | 22 | 22

Kate’s Concepts
Selection Criteria | Concept 1 | Concept 2 | Concept 3
Ease of Use | 4 | 3 | 2
Size & Weight | 3.5 | 4 | 3
# of Adjustments per cycle | 4 | 2.5 | 3

Safety | 3 | 3 | 3

Durability | 3 | 3.5 | 3
Cost Estimate | 3 | 3 | 2
Is it Realistic | 3 | 3 | 2
Total | 23.5 | 22 | 18

Andre’s Concepts
Selection Criteria | Concept 1 | Concept 2 | Concept 3
Ease of Use | 5 | 4.5 | 2
Size & Weight | 2.5 | 4 | 4.5
# of Adjustments per cycle | 4 | 5 | 4

Safety | 3 | 2 | 3
Durability | 2.5 | 4 | 4
Cost Estimate | 2.5 | 3 | 4
Is it Realistic | 3.5 | 3 | 3
Total | 23 | 25.5 | 24.5

### 4. Choose one or a few promising solutions you wish to develop further based on

your evaluation.

After analyzing each concept provided by our team, we have chosen 5 of the best performing concepts to further analyze . Using the same values found in question 3, we created a new decision matrix only containing our highest scoring ideas.

Selection Criteria | Option 1 Anbo’s Design #1 | Option 2 Andre’s Design #3 | Option 3 Kate’s Design #1 | Option 4 George’s Design #1 | Option 5 Lucas’s Design #2
Ease of Use | 4 | 4 | 4 | 3 | 3
Size & Weight | 3.5 | 3.5 | 3.5 | 5 | 2
# of Adjustment s per cycle | 4 | 4 | 4 | 3 | 4

Safety | 3 | 4 | 3 | 3 | 4
Durability | 3 | 3 | 3 | 3 | 3
Cost Estimate | 2.5 | 4 | 3 | 5 | 4
Is it Realistic | 4 | 4.5 | 3 | 4 | 3
Total | 24 | 27 | 23.5 | 26 | 23

Option 1:
The U-Shaped electric toothbrush is a promising concept. It is an innovative device with a brushing process that is fast, easy to operate and can be operated without being plugged into an outlet. Disadvantages noted were the cost, safety and durability.

Option 2:
Andre’s 3rd design is a simple yet effective way to tackle our clients’ needs. It requires only one servo which slightly increases its weight, though ranks high in safety, ease of use and cost.

Option 3:
Kate’s 1st design combines the idea of a mouthguard like toothbrush and a conventional toothbrush. I requires 4 preset positions to allow the client to reach all four quadrants of her mouth, making it user friendly and cuts down on time. The biggest disadvantage with this design would be the cost and that it would be very hard to achieve in the short time frame and constraints we were given.

Option 4:
George’s 1st design is a very inexpensive and simple way in implementing a rotational component on a standard electric toothbrush. Given its lack of features, it can be more strenuous for the user to achieve the desired angle. Constantly using one's teeth to bite and rotate the brush will result in quicker abrasion over time.

Option 5:
Lucas’ 2nd idea of a longer toothbrush is a very realistic design. The additional length would allow the client to reach the back of her mouth with ease and does not require additional servos or technical adjustments. The downfall to this is that the added weight would make it awkward and could be challenging given the clients limited dexterity and gripping abilities.

### 5. Develop a group design concept which is either an integration or modification

of the promising concepts chosen in the previous step, or a brand-new concept created from these ideas. Justify your approach.

The team has decided on a concept that is a combination of small features from multiple designs. Although there was not one design that met satisfactions originally, the team combined multiple small features and used the rotating toothbrush design as a base to improve. The resulting team concept is an electric toothbrush that has three degrees of freedom but only requires 2 servos. The design achieves this by rotating 180 degrees and then flipping over to go from the bottom jaw to the top. The toothbrush uses a regular commercial brush head to ensure the brush is safe for the clients mouth.

6. Visually represent (sketch, diagram, CAD model, etc.) your group concept.


### 7. Provide a few lines explaining your concept’s relationship to the target

specifications, as well as its benefits and drawbacks

Our brush design was decided upon as we believe that it gives our team the best possibilities for achieving our target specifications. While other concepts may have been more effective in function, they were not feasible for our projects limitations. The concept design our team decided upon is what we believe to be a good combination of effectiveness and feasibility.

We also had our target specifications for weight of the device in mind while creating this concept. The fact that we can reduce three degrees of freedom to only servos allows to cut down on weight while still keeping the ease of use that is necessary for the client.

Using only two servos also makes our timing goals more achievable because it simplifies the designing and manufacturing process as well as helping to keep the cost low and within our target specifications. In addition, reducing the amount of joints present in the device reduces the areas where error or failure is most likely to occur.

Conclusion:

After coming together to discuss the multitude of ideas our group had, we worked together to find an effective solution to the problem at hand. By breaking down the required product functions, we were able to develop and analyze concepts that directly solved our problem statement. Using the advice given to us regarding the selection criteria in deliverable B, we were able to further evaluate each design and ensure that all needs were satisfied in the creation of our final design.

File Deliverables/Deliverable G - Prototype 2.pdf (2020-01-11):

Project Deliverable G: Prototype 2 GNG 2101 – Intro. to Product Dev. and Mgmt. for Engineers Faculty of Engineering – University of Ottawa

Date: October 31st, 2019
Group number: Group 10
Group members: Andre Fernette, Anbo Xu, George Abou-Hamad, Kate Ford, Lucas Hubert

Introduction

In this deliverable we will define a new design solution with the intent of presenting it on Design Day. By reviewing the client feedback that we received during our third client meeting, we will outline the most pertinent design deficiencies, allowing us to improve our final design. This will be achieved by creating an additional prototype with said design flaws addressed, helping us get closer to creating a final product.

Upon creating out new prototype, we will conduct tests to analyze our products performance by comparing it to our target specifications. By organizing our results in a tabular format, we can further compare our expected results in relation to the actual results. Doing such will allow us to outline remaining design flaws and assure that come Design Day, we may present our client with a verified solution that is effective at treating our problem statement.

### 1. Summarize the client feedback that you received during your third client meeting for

your first product prototype and clearly state what needs to be changed or improved in your design.

Upon meeting with our client for the third time, we were able to present the improved design and prototype we have created. At the time of our last meeting, we presented the client with our original idea of a customizable toothbrush with two degrees of freedom. The client expressed many concerns that caused us to change to our current design.

The client was very pleased with the changes to the original design. He believes that keeping the toothbrush intact and creating a gimbal style support system is definitely more realistic and has a higher chance of functioning within the short timeframe we have. Notably, our client was pleased by the ergonomics our new chosen toothbrush. Due to the physical constraints of our client, a lighter overall product is a very important metric to take into account. Making this change addressed both weight of our product, as well as decreasing our total found in the Bill Of Materials.

Old Toothbrush | New Toothbrush
Oral-B Vitality FlossAction Electric Rechargeable Toothbrush | GUM Daily Clean Sonic Battery Powered Electric Toothbrush


In summary, our client was overall very pleased with how our latest product design. One suggestion that was provided relating to our current design was to use a Sensor Shield V4 Digital Analog Module for Arduino.

An increase in sturdiness of our device was also discussed. As a team, we plan on delivering a product that is of the utmost quality given the time and financial restrictions we face. By refining our design that will maximize the number of uses possible before breaking down, we grow closer to achieving a solution that works efficiently at solving our client’s problem.

Possible design adjustments for overall ergonomics were also discussed to maximize comfort of our client while operating the device. This included ideas regarding adjustments to the handle of our product appropriately tailored to our clients capabilities.

2 & 3. Based on the feedback, develop a second prototype (or more) which will help you on your way to creating your final product. Document your latest prototype(s) using as many sketches/diagrams/pictures as required and explain the purpose and function of your prototype(s).

Based on the feedback provided, there are a few adjustments we plan on implementing in our next prototype. As discussed earlier, the use of the Sensor Shield V4 Digital Analog Module will be used to connect the servos to our microcontroller. Our old design incorporated a multitude of wires which would have been connected to a breadboard which would then be connected to the Arduino Uno. By using the Sensor Shield we may increase the overall aesthetics while diminishing the total number of separate parts needed.

Old Design | New Design


One major insight our team had when testing our previous prototype was that the connection pieces between the servos were unnecessarily long. The oversized arms created no advantage and led to create forces and stresses on the joints. For this reason we changed the length of the connection pieces to allow for a more compact and efficient device.

Old Design | New Design


As mentioned, maximizing the structural strength of our device is a great concern of ours as well as our client. We noticed that our current design put a lot of stress on our first joint, found above the handle component. This was found to be a significant design flaw as our product needed to be one that was well built, capable of withstanding stress from daily usage. To solve this issue, we plan on adding a circular collar around both pieces. By doing so, we assure that in the case there is an ample amount of stress in one direction of our first joint, we can prevent further flex by having the collar serving as a stopping agent before the damage is done.

Old Design | New Design (idea)


In our previous design, the mounting plate that the driven side of each servo would mount to was missing a feature that would allow us to secure the mounting wing to the servo after the wing had already been attached to the next piece. To fix this design flaw, we have added a bore with a lip for a screw head to sit on to the center of the mounting plate. This will allow the wing to first be attached to the next piece, then a screw can be driven through both the wing and the gimble piece and then into the servo spline. This will greatly improve the integrity of the device as it “sandwiches” all three pieces together with a single screw, in addition to the screws that hold in place the wing to the 3D printed gimbal piece.

Old Design | New Design


Another revisment to aid in assembly that we made in response to our previous prototype was slots for wires. In the previous design, the servos fit very well in the spaces designed for them. However, when inserting the servos, a small grove had to be filed in to allow the wires to slide in with servo. To fix this we have designed a small slot that gives the wires clearance to slide down with the servo until they meet the exit port designated for the wires.

Old Design | New Design


Upon prioritizing the functionality and structural integrity of our device, we would also like to further increase the quality of our clients experience when brushing their teeth. By refining the handles structure, we will be able to increase our clients grip, facilitating the handling of the device. We’re currently in the ideation stage of finding an effective solution for our client. These ideas include adding a shape similar to the handle of a mug. This can be achieved through by 3D printing a new handle or purchase and attach a nylon strap to the handle

Old Design | New Design (ideas)


### 4. Carry out prototype testing, analyze and evaluate performance compared to the

target specifications developed in Project Deliverable B and document all your testing results and prototype specifications. Present your testing in an organized, tabular format that shows expected versus actual results.

Testing Criteria | Expected | Actual
Weight | 200g | 163g
Adjustments per cycle | 6 | 4
Coefficient of friction on the handle | 0.2 | 0.46
Degree of rotation | 180° | 360°
Torque provided by the servos | 0.005Nm | 0.004Nm
Battery life of the power bank | 5h | 3.4h
Cost Estimate | $64.49 | $82.25

Taking advice from our client, we added Sensor Shield V4 Digital Analog Module for Arduino to our bill of material which costs $22.25, making the cost estimate higher than what we had in the original plan. Using our updated gimbal design, now the device is able to achieve a degree of rotation of 360°, which can make the process of brushing the client’s teeth more convenient and efficient for her.

As the functionality of our new prototype did not differ much from our previous prototype, we decided to prioritize working on the programming of the arduino. As we are still waiting on certain components to independently use the arduino, we accessed resources provided on campus, this included makerlab. There, we were able to begin the programming process, attempting to get the servos to move in a timely fashion. Without much success, we were still able to do a significant amount of debugging, and got one servo to rotate. Upon further debugging, we plan on developing and implementing the entire sequenced cycle for one session of tooth brushing.

### 5. Outline what your team intends to present on Design Day and how you intend on

verifying that your “Solution Works Really Well”.

On design day, our team intends to present a device that effectively solves our client’s problems. This device will be one that is easy to use, sturdy and will allow our client to brush all areas of their teeth independently, without the aid of a nurse.

We plan on achieving this by developing a comprehensive prototype used to conduct further tests. By performing a multitude of realistic scenarios our client may experience upon using the device, we are able to collect valuable data regarding the expected versus the actual functionality of our device. This will inevitably minimize the amount of uncertainties that could potentially damage the device, rendering it useless.

Conclusion

This week, we were able to further refine our design solution intended to be presented on design day. Summarizing our client meeting feedback enabled us to address our design flaws, allowing us to further improve our final design. Particularly, alterations in the wiring of the device, structural integrity of the device, as well as user handling were conducted. We organized our results in a tabular format, facilitating the comparison of our expected results in relation to the actual results. We were also able to begin the coding process of our arduino using the required tools provided in makerlab.

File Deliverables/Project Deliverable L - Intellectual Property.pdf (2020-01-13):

Project Deliverable L: Intellectual property Search GNG 2101 – Intro. to Product Dev. and Mgmt. for Engineers Faculty of Engineering – University of Ottawa

Date : December 5th 2019
Group number: Group A10
Group members: Andre Fernette, Anbo Xu, George Abou-Hamad, Kate Ford, Lucas Hubert

Introduction

Intellectual property (IP) refers to the creations of the mind, such as inventions; literary and artistic works; designs; and symbols, names and images used. Laws concerning intellectual property are important as they set businesses apart from competitors, provide an important revenue stream through sales and licensing of creations and promote innovation. Without these protection laws, businesses and individuals would not fully benefit from their inventions, focusing less on research and development, thus negatively impacting the progression of humankind.

In this deliverable we will investigate the various intellectual properties related to our project and explain the importance they have on maintaining the integrity of our product. We will do so by making use of a variety of intellectual property databases such as the Canadian Intellectual Property Office, the United States Patent and Trademark Office, Google Patents and freepatentsonline.com.

1 - Explore intellectual property databases to identify at least three intellectual properties related to your product.
2 - Describe the relationship that exists between these intellectual properties and your product.
3 - Explain the importance of these intellectual properties with regard to your product and the impact they could have on your success.
4 - Discuss the way in which your team intends to manage intellectual property created with your product, assuming you decide to market your product.

Our device can be broken down into various streams of innovative assets by which work synergistically to provide desired functions to our clients. Upon exploring the various aforementioned databases, our group was able to identify varying types of intellectual property rights related to our product. These intellectual properties included: “trademarks, patents including industrial design rights and utility rights and open-source licensing”.

Trademark

Trademarks are a type of intellectual property consisting of a recognizable sign, design, or expression legally registered to identify products of a particular source from those of others. During the development of our device, our team decided to brand our product naming it “Ergobrush” as a means to more effectively market ourselves and stand out amongst the competition. Among other things, we also decided on creating a slogan for our device to give potential users a quick rundown of the device’s utility, our slogan is “The Leading Adaptive Toothbrush For Your Accessibility Needs”. We also intend to create a logo to accompany our brand.

Trademarking our product name, logo and slogan will offer protection to our brand and deter others from infringing upon our efforts. It will also carry its own benefits to the general public by encouraging us to uphold quality product and service standards and provide a sense of reassurance to consumers through consistency in a brand they can trust. This will build an ongoing relationship between our company and the public as well as prevent other companies from misleading customers through the use of a similar name or slogan.

We will register a trade-mark for our brand name, logo and slogan. This will be achieved by filing an application through the Canadian Intellectual Property Office (CIPO). As we intend to market and distribute our product globally, we will also file for trademark registrations internationally. This will be done by referring to the International Trademarks under the Madrid Protocol. Once completed, we will maintain our trademark registrations by ensuring each renewal fee is paid in full prior to its expiration date.

Patent

Patents are a form of intellectual property that legally provides its owner the right to exclude others from manufacturing, using, distributing or importing an invention for a given period of time. A patent is a temporary limited legal right granted to an inventor by a government body averaging a period of 20 years. Patents are a valuable business asset as they credit the innovators work and generate the ability to claim royalties from anyone who infringes on the patent.

We plan on patenting the utility of our device which includes but is not limited to the three degrees of freedom it provides, the hand held design that extends to the toothbrush, the disposable toothbrush bristles and electrical design that powers the device.

We also plan on filing a Design Patent which will serve to protect the visual design of our product. This will consist of visual features of shape, configuration, pattern or ornament used in the production of our finished product created by hand, tool or machine.

It is of great importance to file these patents with regard to Ergobrush for the inevitable impact it will have on our products success. A patent will give us the ability to prevent competitors from reverse engineering our manufacturing process and copying our design. Without necessitating the same investments in research in development (R&D) as we have, these competitors could easily maintain strong profit margins while distributing our product at a lower price.

As our patent will protect our technology for 20 years, we established a long-term business model suitable for this criteria. Using a razor-blade business model will provide the required time to fully optimize our design and competitively market our product
come the patents expiry. For this model, our “bait” product will be the main device component while the “hook” will consist of the patented disposable toothbrush heads. Conducting extensive R&D throughout the 20 years will allow us to greatly diminish the cost of our “bait” device ensuring competitiveness. This time period will also allow us to establish key partners, customer relationships and key activities and resources further giving us the required advantage to dominate our competitors.


The Design and Utility Patent will be filed by writing an Invention Disclosure which will describe the invention, list unique features, list all inventors, relevant literature/patents, dates and records including any data documenting the invention. We will also conduct preliminary patent research to find related patents. This will be done by searching for keywords from Invention Disclosures, using a guide for patent scope and descriptions that will include all relevant patents in list of relevant background to invention.

Open-source Licensing

Open-source and Free Software licenses consist of free software legally permitting the user four essential freedoms. These freedoms including running the program for any desired purpose, study the functionality of the program by modifying it and accessing the source code, redistributing copies of the original program and of the modified version.

Open-source licensing relates to our product as we currently utilize Arduino Software to control and operate our device. Arduino software and hardware is registered under a Creative Commons license which permits anyone to produce copies of the boards, redesign and sell the boards that copy the design. Using technology under this particular license provides the liberty to not have to pay a license fee or ask permission to use the software. By using this software we will be able to market our product at a more affordable price through the creation of our own microcontrollers, avoiding royalties.

One condition that accompanies Creative Commons licenses is that if we do republish the reference design, we must give credit to the original Arduino group. Additionally, our new modified boards must be licensed under the same or a similar Creative Commons license to ensure that our modified version will be equally open-sourced to the public.

Conclusion

To conclude, intellectual property is a vital concept and model to be followed that will ensure the prosperity and protection of inventions marketed to the public. In this deliverable we were able to identify the intellectual properties and describe the relationships that exist with our product. We also further defined the importance that these intellectual properties hold in regards to our product and brand success by discussing the ways in which our team intends to manage intellectual property in the marketing of our product. We found that intellectual property personally affects our brand through trademarking, patenting through designs and utility, as well as the permission to utilize pre-existing software for profit.

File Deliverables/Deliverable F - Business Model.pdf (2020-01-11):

Project Deliverable F: Business Model GNG 2101 – Intro. to Product Dev. and Mgmt. for Engineers Faculty of Engineering – University of Ottawa

Date: October 24th, 2019
Group number: Group 10
Group members: Andre Fernette, Anbo Xu, George Abou-Hamad, Kate Ford, Lucas Hubert

Introduction

In this deliverable we will identify and describe a potential business model that will be well suited in commercializing our team’s product. We will develop a business model by answering the how, what, who and how much of our product. We will also describe and comment on the core assumptions that we have made in developing our business model and its feasibility.

### 1. Identify and describe a type of business model that would be well suited to

commercializing your team’s product. Discuss the reasons for your choice.

The purpose of a business model is to describe how an organization creates, delivers and captures a multitude of values. These values include, but are not limited to: economic, social and cultural values. To maintain the successful operation of a business, a key business model must be appropriately designed to identify revenue sources, a customer base, products, and thoroughly address its details of financing.

Upon reviewing the multitude of predefined business models, it was pivotal for our group to select a model that would ensure the short and long term success of our company. As our product is a handheld device that provides assistance to individuals with mobility impairments, we decided that our ideal business model would be the Razor-Blade model.

The Razor-Blade business model, also known as the Bait & Hook model, is a system wherein the basic product is sold at a low price or given to the consumer for free in order to increase sales of a complementary good. As the basic product cannot be used without the complementary component, this confines the consumer to the business’ ecosystem, increasing the company’s profit in the long term.


https://bmtoolbox.net/patterns/bait-and-hook

As a group, we decided the hook of our model will be the handheld device that performs the required rotations to brush all areas of the teeth. This device will be sold at a reasonable price, providing affordability to our targeted demographic and maintain overall market competitiveness. We will determine this price through market analysis, surveys and benchmarking.

The complementary product that will serve as the bait will be a customized toothbrush head that attaches to the top of our device. We found this to be the ideal component to serve as bait since the bristles of a toothbrush are statistically the component that will deteriorate and lose its utility first. To add, this also falls within guidelines from the American Dental Association (ADA) who recommend that a toothbrush be replaced approximately every three to four months.

We plan on adjusting our product design to ensure all components of our device stem from our production facilities as our current minimum viable product requires the use of an external toothbrush purchased from a third-party. In order to prevent other companies from profiting off our design, we will file in a patent that will grant exclusive rights to manufacture and distribute the device and its unique toothbrush head.

### 2. Fill in a business model canvas by answering the how, what, who and how

much of your chosen business model.


The business model canvas is a tool that helps design and discuss new business models. It consists of nine building blocks that organize and answer the how, what, who and how much.

The key partners, key activities and key resources describe the “how” aspect of our model. The key resources define the infrastructure that will enable us to create and deliver value as well as show which assets are indispensable. The key activities show what is needed to be able to perform efficiently while the key partners show who can help us leverage our business model.

The “what” consists of the value proposition which identifies the problems we are addressing and why our customers will be attracted to our product. This is a crucial step in convincing potential customers to choose our product rather than similar offerings from our competitors.

The “who” is broken down into the customer relationships, channels and customer segments. The customer relationships outline the type of relationship we are establishing with our customers. The channels define how we plan on delivering our product to our client while the customer segments consist of all the people and organizations for which we are creating value.

The “how much” is split into the cost structure and revenue streams. The cost structure addresses the type of costs our business will be subjected to. This includes fixed, variable and economies of scale. The revenue stream make clear how and through which pricing mechanisms our business model will capture value through pricing and utility of revenue systems.

### 3. Describe the core assumptions that you have made in developing your

business model and comment on its feasibility.

In order to make our business plan as realistic as possible, several core assumptions were made regarding the development of our project.

First, we assume that we will have access to enough capital to launch our product in the market and get our patent approved. As these things tend to require a significant amount of time and capital, we must assume that these are expenses our business can afford. Given our Razor-Blade business model, we must also assume that we will have enough capital to keep the business afloat until our sales volume increases with time. This is due to the fact that our basic product will have a minute profit margin, in hopes of increasing long-term profits through the sale of our complementary product.

Upon conducting market research, we concluded that a sufficient number of customers will be willing to buy our product. Given these numbers, we believe that this will be sufficient in generating enough profits to maintain product production costs. Our costs include overhead costs, manufacturing, marketing and rental fees. These costs will be paid off assuming that we will sell enough units at a price level that matches the desire of the market.

Another core assumption we have made in the development of our business plan is that we have the expertise and technical resources required to run this business profitably as soon as possible. Things like patenting, legal issues, marketing strategies and making a sustainable budget will be delivered by us as a team in a way that will allow us to make the business profitable in the short to medium run.

Those assumptions demonstrate that our business model is feasible since we will fill a gap in the market that has not yet been exploited and reach an ample amount of customers to generate enough sales. By applying these core assumptions, we believe we can generate enough profits to sustain our business in the long term.

Conclusion

Upon analyzing the various types of business models, we decided that a Razor-Blade business model would be optimal for our product. The base of the device will hook our consumers to our product while the disposable toothbrush heads will serve as the bait, providing a long term reliable source of income. We then developed a business model canvas addressing the nine building blocks that organize and answer the how, what, who and how much of our business model. Finally, we described and commented on the core assumptions our team has made in developing our business model and its feasibility.

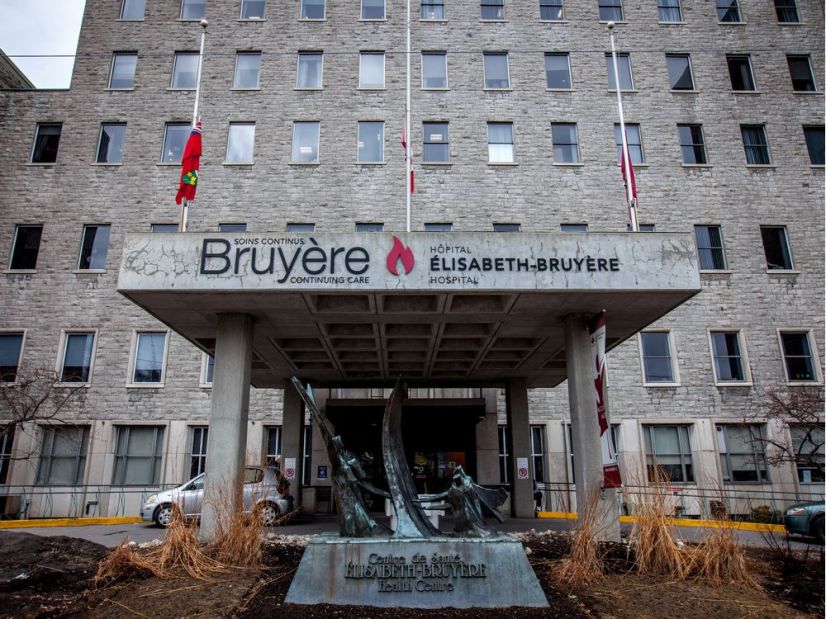
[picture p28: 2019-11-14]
img/stvincent.jpg

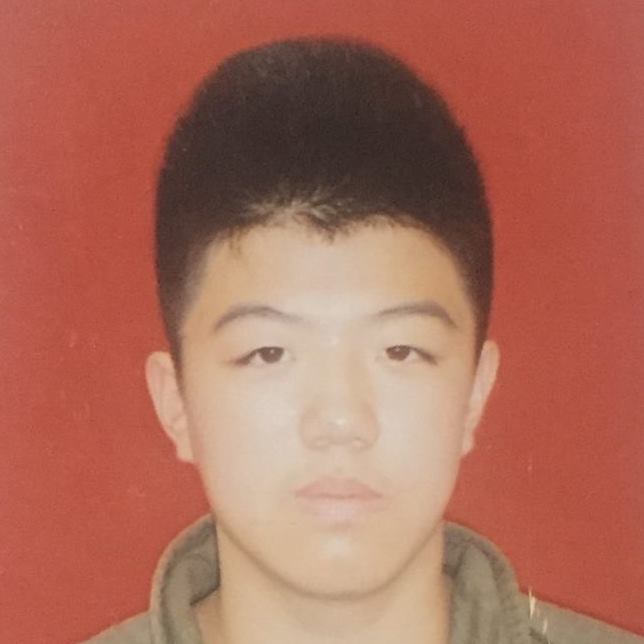
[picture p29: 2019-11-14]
img/anbo.jpg

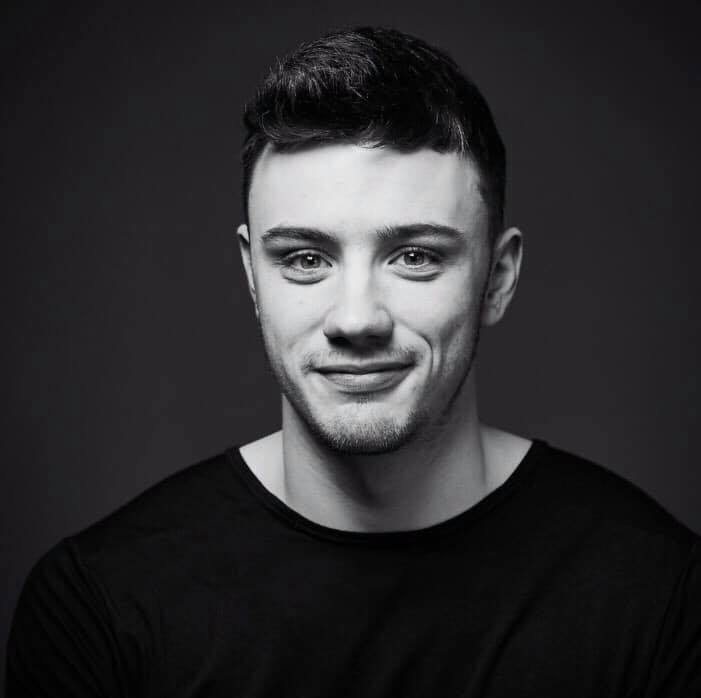
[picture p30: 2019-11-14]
img/lucas.jpg

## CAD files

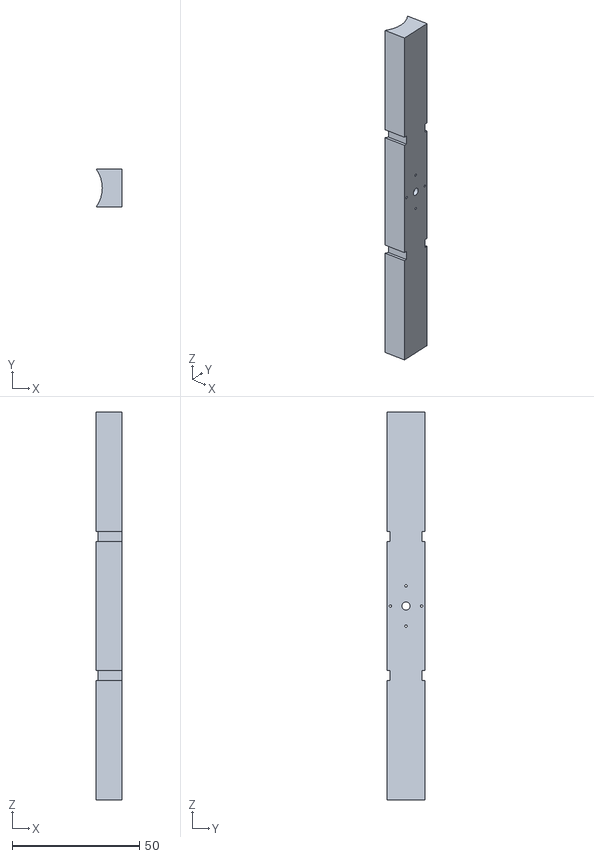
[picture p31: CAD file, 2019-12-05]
3D Models/4-BrushHandle.STL
10.2 x 15.0 x 152.4

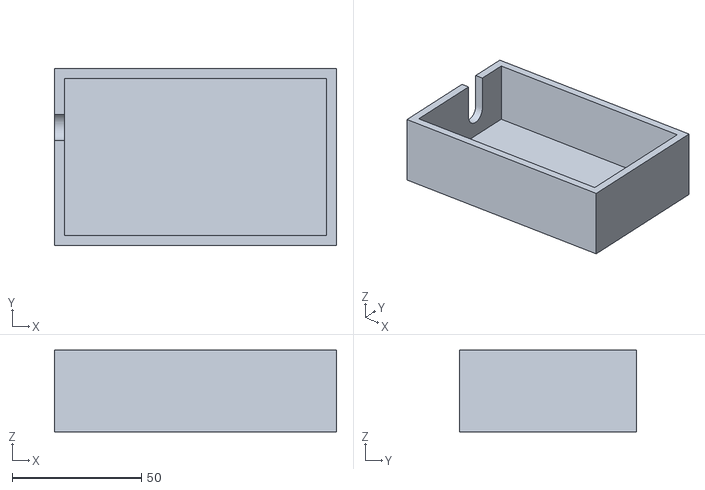
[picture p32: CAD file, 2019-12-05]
3D Models/5-BoxCase.STL
109.2 x 68.6 x 31.8

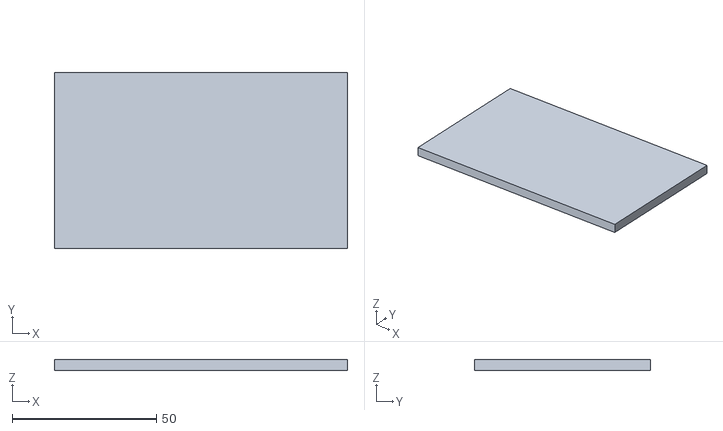
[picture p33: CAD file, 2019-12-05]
3D Models/6-BoxLid.STL
101.6 x 61.0 x 3.81

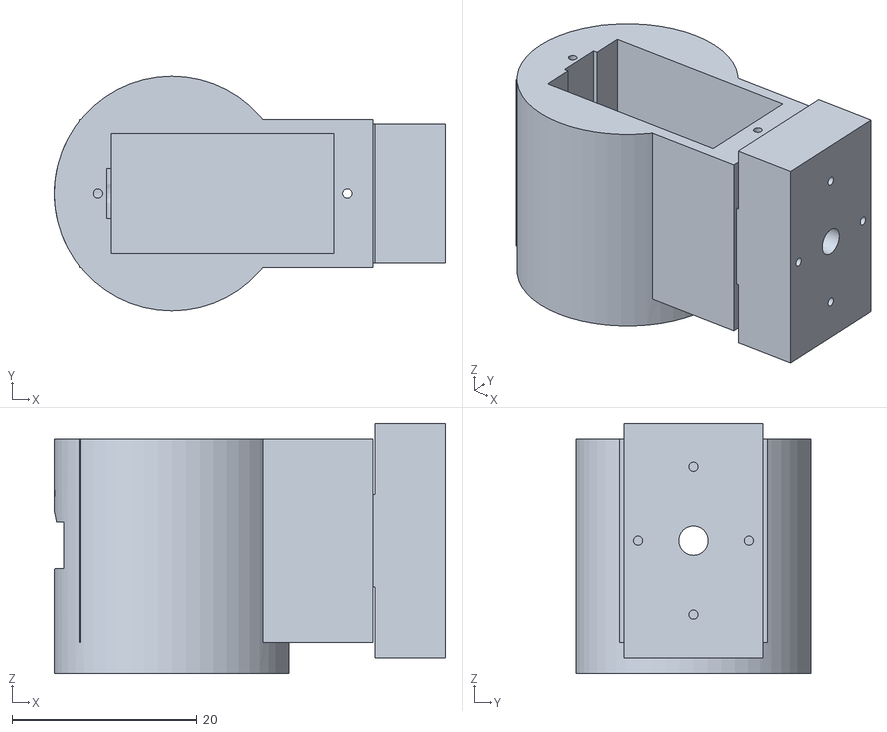
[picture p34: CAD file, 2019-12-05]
3D Models/3-JointTwo.STL
42.3 x 25.4 x 27.1

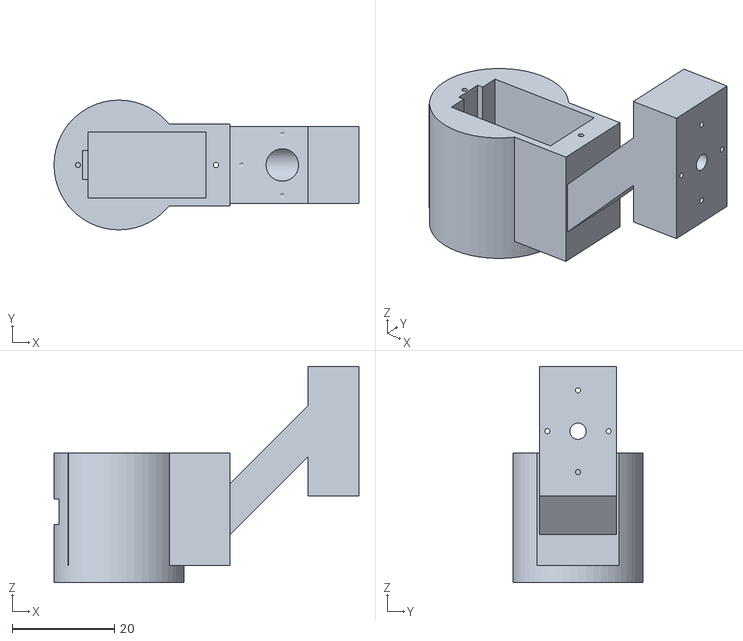
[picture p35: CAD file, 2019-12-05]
3D Models/2-JointOne.STL
59.7 x 25.4 x 42.3

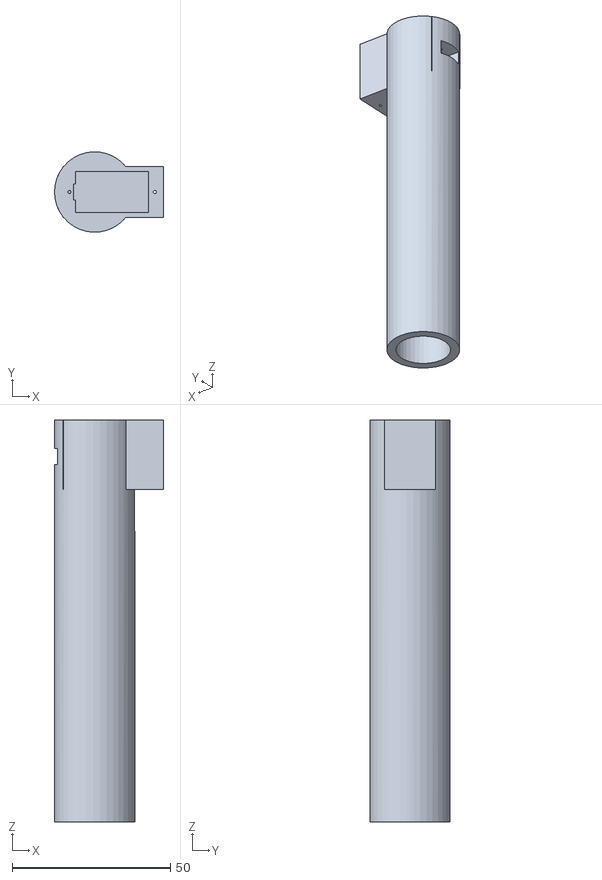
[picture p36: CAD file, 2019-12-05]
3D Models/1-Handle.STL
34.5 x 25.4 x 127.0

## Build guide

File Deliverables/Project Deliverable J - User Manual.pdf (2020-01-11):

# Ergobrush: Rotating Electric Toothbrush

## The leading adaptive toothbrush for your accessibility needs

# Project Deliverable J: User Manual GNG 2101 – Intro. to Product Dev. and Mgmt. for Engineers

## Faculty of Engineering – University of Ottawa

## Professor: Hanan Anis Teaching Assistant: Mana Azarm Project Manager: Michael Qi

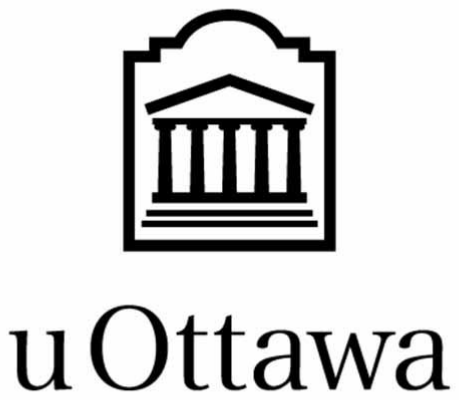
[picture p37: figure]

## Group A10

## George Abou-Hamad Anbo Xu Lucas Hubert Kate Ford Andre Frenette

## December 4th 2019

## Abstract

Our group was given the task to develop a device that would provide assistance in the rotation of an electric toothbrush for our client MK. As our client has limited arm mobility, this device would provide her with independence when brushing her teeth. By utilizing the Iterative Engineering Design Process, our group would be well equipped to create a viable solution for our client come design day. We first began our journey by interviewing our client to gain insight on the various needs and wants they wished to be fulfilled. From the data collected, we created a list of target specifications and metrics to which served as a blueprint in our problem refinement loop phase.

Benchmarking was an important factor in further refining our specifications and metrics while also greatly influencing our creativity in generating solutions. Conducting a feasibility study allowed us to identify our constraints by analyzing the Technical, Economical, Legal, Operational and Scheduling constraints at hand. A functional decomposition was done to break down the smaller basic sub-functions identifying the subsystem boundaries using our design criteria. We generated solutions and created a weighted decision matrix to determine the feasibility of each concept.

With the results obtained, a new design was generated and a bill of materials was created. Our initial solution consisted of a traditional rechargeable toothbrush that would be modified to provide two axis of rotation, giving the bristles the ability to rotate and bend forward. Upon presenting the idea to our client, we were met with multiple concerns regarding the complexity, safety and overall lack of feasibility of this device.

Using the client feedback received, we reiterated through the ideation process and created a new solution. Our new prototype would consist of a hand-held device that would attach to our clients toothbrush. It would offer three axis of rotation allowing our client to fully brush her teeth without the need to modify a pre-existing toothbrush.

Upon receiving approval of our new concept, we iterated through many prototypes, testing our assumptions while continuously optimizing our design. Come design day, we presented our fully functional comprehensive prototype branded Ergobrush. The device uses timed positioning sequences that rotate an electric toothbrush, allowing our client to brush all areas of her teeth without necessitating hand movement.

## Table of Contents

List of Tables | 5
Introduction | 6
User Manual | 7
Features and Functions | 7
Capabilities | 9
Prototype Development | 9
Product Composition | 9
Product Assembly | 11
Device Operation | 14
Safety Guidelines and Troubleshooting | 16
Design Files | 17
Conclusion | 19
Future Work | 19
Bibliography and Appendices | 20

# List of Tables

Table 1 : Product Features and Functions | 7

Table 2: Product Components
9
Table 3: Product Specifications | 9
Table 4: Product Assembly Steps | 11
Table 5: Device Overview | 14
Table 6: Design Files and Explanation | 16

## Introduction

Self-sufficiency is a common goal amongst the general population as no individual is better at assessing one’s needs than themselves. This is particularly important for individuals who hold certain disabilities that interfere with their ability in satisfying their basic needs. Creating assistive devices that can be used by individuals with disabilities will enable them to attain a sense of autonomy. Provided with the proper tools, these individuals will feel less ostracized, attaining a sense of freedom and control over their own lives.

One in five Canadians have a physical disability impacting their daily lives. These disabilities often leave the individual with hindered independence, requiring assistance to complete common tasks such as brushing one’s teeth. Our client is a patient at the Saint Vincent Hospital in Ottawa, Ontario, Canada. While she is fairly capable and strives to be as independent as possible, she has a hard time brushing her teeth as she is lacking the ability to fully rotate her wrist.

Ergobrush was created to provide a feasible solution for individuals with limited arm and hand movement that wish to brush their teeth independently. By designing an adaptable hand-held toothbrush that emulates a natural brushing experience, Ergobrush offers the assistance necessary while simultaneously providing the satisfaction of brushing one’s teeth autonomously. Ergobrush will also reduce the workload on nurses and support staff.

Ergobrush is the only hand-held device that provides three axis of rotation, enabling the user to brush all areas of their teeth effortlessly. It is built using inexpensive, durable yet light-weight, fully recyclable materials, making it far more affordable than any other assistive toothbrush. Using arduino technology, the device can be easily reprogrammed to cater to specific needs and preferences. Also reduce workload on support staff.

## User Manual

## Features and Functions

Table 1 : Product Features and Functions

Feature Visualization | Function
Three Degrees of Freedom | Three degrees of freedom enable the toothbrush to achieve the various positions required to brush all areas of the teeth. This is achieved without requiring the user to move their hand whilst operating the device.
Timed Interval | Using pre-programmed time dependent sequences increases the accessibility by enabling the user to achieve desired positions without necessitating the use of any buttons.
Vibrating toothbrush | Scientifically proven to reduce plaque and gingivitis when compared to a manual toothbrush. According to a meta-analysis study conducted by Cochrane Oral Health Group, using a powered toothbrush compared to a manual one was proven to have a 21% reduction in plaque and 11% reduction in gingivitis after three months of use.
Customizable Positioning | The user is able to update their device to cater to their preferences. Provides a cost-free option to add, remove or adjust various positions and time spent per position. This provides a fully customizable device tailored to each individual's unique needs.
Energy Efficient | Using low energy dependent technologies allow for an extended number of uses before needing to replace or

| recharge the battery.
ON/OFF Switch | Providing a On/OFF switch simplifies user experience, increasing overall accessibility as the device does not require any pre-existing knowledge to operate.
Low Maintenance | Device requires minimal maintenance. User is able to replace batteries with ease. Batteries used are AAA and 9V which are relatively inexpensive and widely available.
Low Cost | Using widely available, inexpensive materials enables the cost of the device to be competitive and low. Directly increasing the accessibility of the device to aid low-income earning individuals. This also creates a ripple effect in the cost of overall accessibility devices as it pressures competing products to lower their product costs.

## Capabilities

Table 2 : Product Specifications

Cost of manufacturing | CAD$96.58
Mass of Product | 175g
Uses per charge | >15
Degrees of freedom | 3
Cycle Runtime | Variable

## Prototype Development

## Product Composition

Ergobrush is composed of various sub-systems that work synergistically to effectively rotate and position an electric toothbrush. Notably, the device in its entirety can be broken down into two categories: 3D printed components and the purchased components. The 3D printed pieces are composed of ABS filament and serves as the device’s casing and structure. The purchased components power the device and contain the various technologies used in changing the toothbrushe’s position.

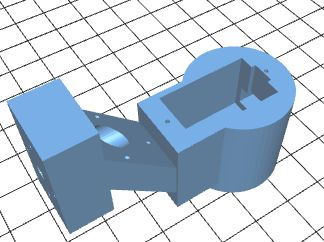
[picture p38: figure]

Table 3: Product Components

3D Printed Components

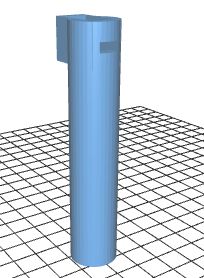
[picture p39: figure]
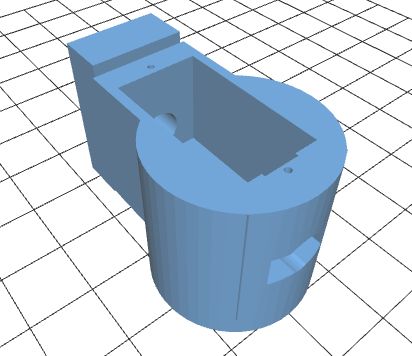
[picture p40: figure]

Handle | Joint 1 | Joint 2

Toothbrush Stabilizer | Arduino Case | Arduino Case Lid

Purchased Components

Micro Servo + Horn x3 | Servo Extension Cord | Arduino Uno r3
9v Battery Holder with ON/OFF Switch for Arduino | Sensor Shield V4 Digital Analog Module for Arduino | GUM Daily Clean Sonic Battery Powered Electric Toothbrush
9 Volt Battery | AAA Battery | Zip Ties x2

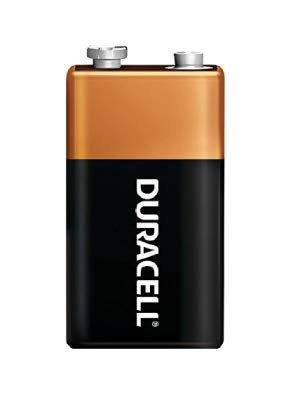
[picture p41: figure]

## Product Assembly

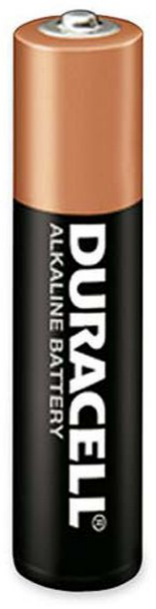
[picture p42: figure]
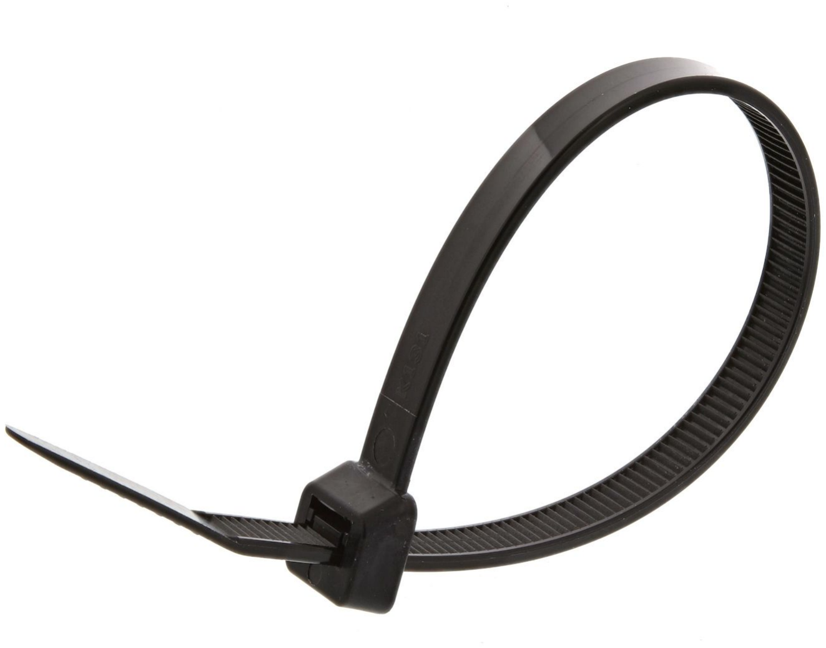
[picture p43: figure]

The assembly of our prototype is relatively easy and straightforward due to its minimal and ergonomic design. The product assembly can be broken down into a few simple steps.

Table 4: Product Assembly Steps

Step 1

Begin by adding a servo extension cord to each servo. This will ensure that the wire can be passed through the handle and reach the arduino.

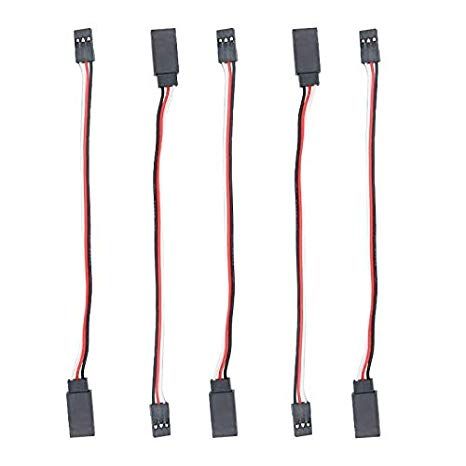
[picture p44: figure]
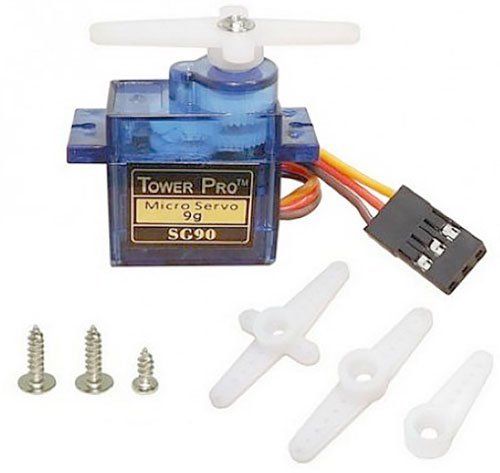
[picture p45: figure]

+

Step 2

Insert a micro servo in the handle piece, joint 1 piece and joint 2 piece. Passing the servo wire through each joint exit hole and into the main exit hole found in the handle.

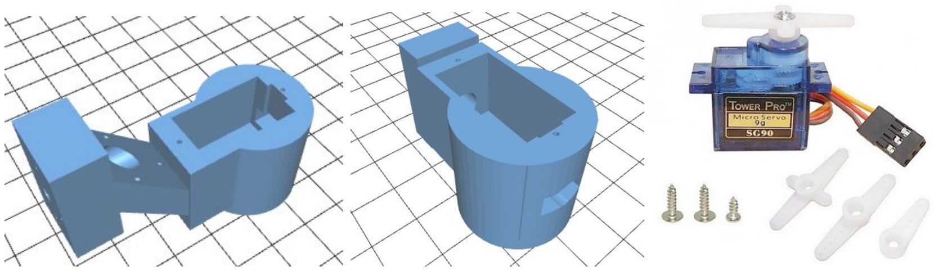
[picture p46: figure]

Step 3

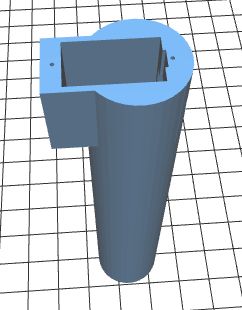
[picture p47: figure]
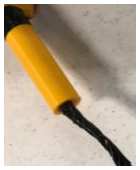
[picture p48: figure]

Attach the toothbrush to toothbrush stabilizing piece. This is done using zip ties and tape if necessary.

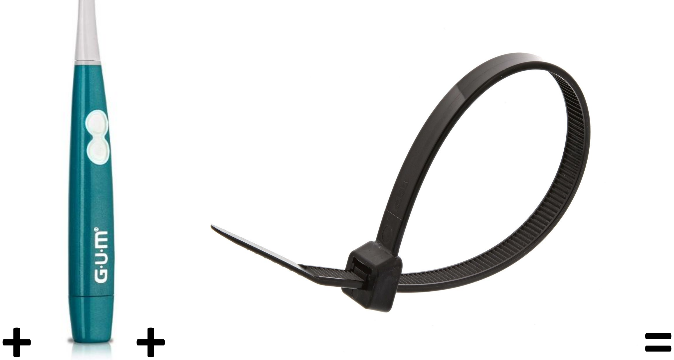
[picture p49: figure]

Step 4

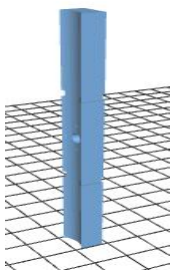
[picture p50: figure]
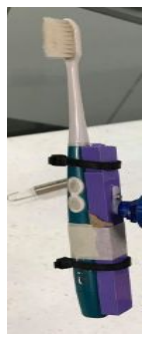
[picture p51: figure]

Attach each micro servo horn to its designated piece as stated below:
4.1 - Screw the handle piece’s micro servo to the base of joint 1.
4.2 - Screw joint 1’s micro servo to the base of joint 2.
4.3 - Screw joint 2’s micro servo to the center of the stabilizing piece opposite of the toothbrush.
Together, the device should look like this:

Step 5

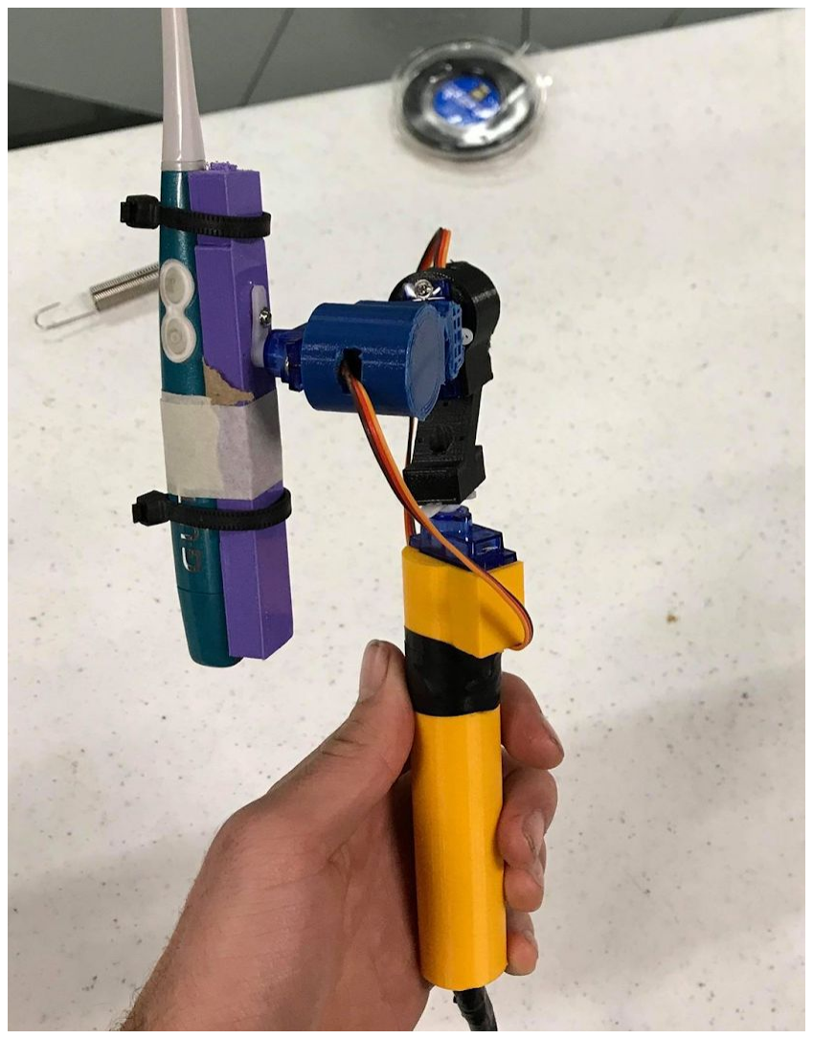
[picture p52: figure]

Connect the micro servo cables to the Arduino shield and attach the Arduino Shield V4 to the preprogrammed Arduino Uno r3 as stated below:
5.1 - Micro Servo 1 to shield slot A0
5.2 - Micro Servo 1 to shield slot A1
5.3 - Micro Servo 1 to shield slot A2
5.4 - Attach the Arduino Shield V4 to the Arduino Uno

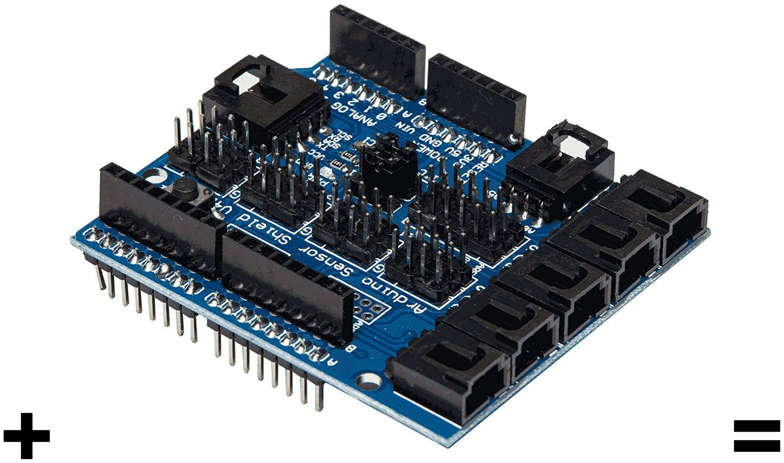
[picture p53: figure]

Step 6

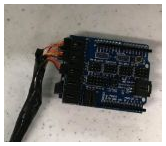
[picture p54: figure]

Connect the 9 Volt battery case to the the Arduino using the DC power cord and add the protective casing to the Arduino Uno r3 and Arduino Shield V4.
If your Arduino Uno r3 is not preprogrammed, you may consult the code provided in the Design Files table. To learn how to install and program your Arduino Uno watch this video: https://www.youtube.com/watch?v=5OtMqr5hGjE

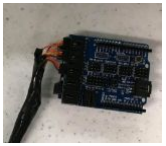
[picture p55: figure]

+ | + | +

=

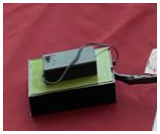
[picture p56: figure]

Step 7

Insert 9 Volt battery in 9 Volt Case and AAA Battery in the electric toothbrush.

## Device Operation

The device operates by rotating each servo receiving directions from the Arduino Uno r3. Each servo movement is programmed to have a certain degree and delay. When coded in a certain sequence, this enables the toothbrush to hold desirable positions, allowing the user to brush all areas of their teeth while keeping their arm still. Simply begin by wetting and applying toothpaste to the brush, powering the toothbrush on and finally turning on the arduino via the 9 Volt power switch. Once you have completely brushed your teeth, power off the arduino and toothbrush and rinse the bristles.

Table 5: Device Overview

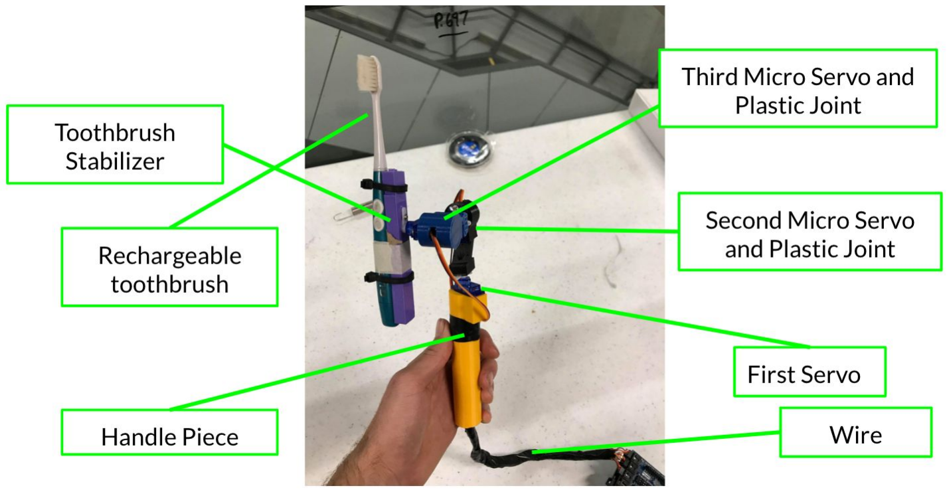
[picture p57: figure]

Main Device

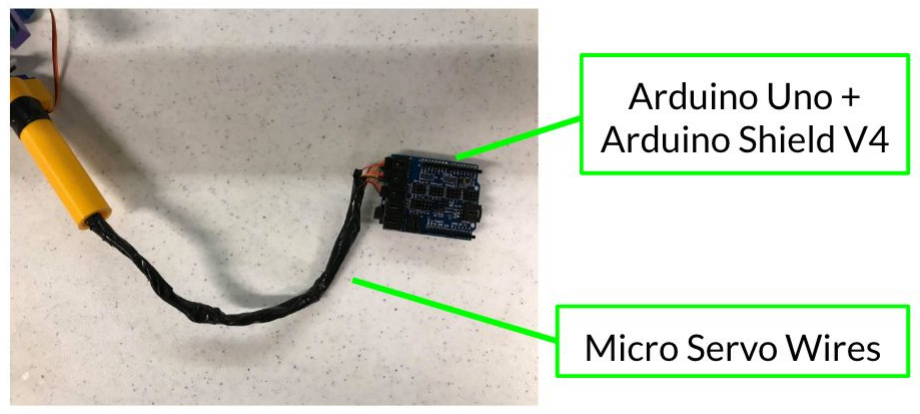
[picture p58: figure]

Microcontroller

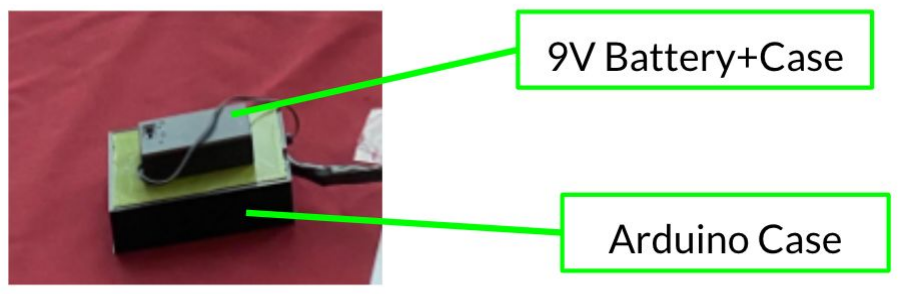
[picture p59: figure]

Microcontroller With Cover and Battery

Arduino Code

## Safety Guidelines and Troubleshooting

As the device will be used near water, it was essential to design a water resistant device to ensure user safety. The device operates on a very low voltage and has it’s main electrical components secured in a water resistant casing, distant from the toothbrush. This provides safety to the user and ensures the products longevity. If the user desires to power off the device at any time, ensure that the 9 volt switch is off and unplugged from the arduino. As the device is programmed to begin at the same position at every initial use, if any issues were to occur during product operation simply troubleshoot by reset the device by turning the power off and on.

# Design Files

All Files can be found on our MakerRepo and GitHub page.

MakerRepo: https://makerepo.com/GeorgeA/gng2101a10-adaptable-toothbrush-fall-2019 GitHub: https://github.com/ergobrush/ergobrush.github.io

Table 6: Design Files and Explanation

Design File Name | Explanation | File Link
1-Handle.STL | The 3D model of the handle stored in .stl file format | https://github.com/ergobrush/ergobrush.github.io/blob/master/3D%20Models/1-Handle.S TL (https://github.com/ergobrush/ergobrush.github.io/blob/master/3D%20Models/1-Handle.STL)
2-JointOne.STL | The 3D model of the first joint stored in .stl file format | https://github.com/ergobrush/ergobrush.github.io/blob/master/3D%20Models/2-JointOne. STL (https://github.com/ergobrush/ergobrush.github.io/blob/master/3D%20Models/2-JointOne.STL)
3-JointTwo.STL | The 3D model of the second joint stored in .stl file format | https://github.com/ergobrush/ergobrush.github.io/blob/master/3D%20Models/3-JointTwo. STL (https://github.com/ergobrush/ergobrush.github.io/blob/master/3D%20Models/3-JointTwo.STL)
4-BrushHandle.STL | The 3D model of the toothbrush stabilizer stored in .stl file format | https://github.com/ergobrush/ergobrush.github.io/blob/master/3D%20Models/4-BrushHa ndle.STL (https://github.com/ergobrush/ergobrush.github.io/blob/master/3D%20Models/4-BrushHandle.STL)
5-BoxCase.STL | The 3D model of the Arduino box case stored in .stl file format | https://github.com/ergobrush/ergobrush.github.io/blob/master/3D%20Models/5-BoxCase. STL (https://github.com/ergobrush/ergobrush.github.io/blob/master/3D%20Models/5-BoxCase.STL)
6-BoxLid.STL | The 3D model of the Arduino box lid stored in .stl file format | https://github.com/ergobrush/ergobrush.github.io/blob/master/3D%20Models/6-BoxLid.S TL (https://github.com/ergobrush/ergobrush.github.io/blob/master/3D%20Models/6-BoxLid.STL)
Brush.ino | The Arduino code that is used to set the operating patterns of the toothbrush stored in .ino file format | https://github.com/ergobrush/ergobrush.github.io/blob/master/brush/brush.ino (https://github.com/ergobrush/ergobrush.github.io/blob/master/brush/brush.ino)

# Conclusion

In conclusion, Ergobrush was designed and created to provide individuals with limited arm and hand mobility a feasible solution to brush their teeth independently. We came up with the idea of designing Ergobrush after meeting many times with our client MK and listening to her needs. We then moved on to generating ideas and prototyping to get to our final design we are presenting. Its movement capacity, composed of three axis of rotation is the only hand-held device enabling the user to brush all areas of their teeth effortlessly. Using arduino technology, the device can be programmed to fit the needs of our current client MK and implement the teeth brushing sequence that she prefers.

## Future Work

In the future, having more resources and time to work on this design would allow us to implement several changes to make Ergobrush more accessible and adaptable to a variety of clients. With more financial resources, we would be able to use better servos to have more stable joints to improve the durability of the toothbrush. Also, with more time, we could implement more functions and programs for the microcontroller to be able to offer a wider range of toothbrush sequencing and programming options to various clients. That way, Ergobrush could be programmed for a variety of clients and we could design personalized brushing sequences based on their specific needs.

# Bibliography and Appendices

Number of Individuals with Disabilities in Canada https://www150.statcan.gc.ca/n1/pub/89-654-x/89-654-x2018002-eng.htm Psychological implications of lack of independence and mental health: https://www.ncbi.nlm.nih.gov/pmc/articles/PMC4046637/
Vibrating toothbrush health benefits meta analysis https://www.cochrane.org/CD002281/ORAL_poweredelectric-toothbrushes-compared-to-man ual-toothbrushes-for-maintaining-oral-health (https://www.cochrane.org/CD002281/ORAL_poweredelectric-toothbrushes-compared-to-manual-toothbrushes-for-maintaining-oral-health)
Project Deliverables : https://github.com/ergobrush/ergobrush.github.io/tree/master/Deliverables

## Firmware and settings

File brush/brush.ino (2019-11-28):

#include <Servo.h> 
Servo s0; 
Servo s1; 
Servo s2; 

void setup() {
  // put your setup code here, to run once:
  pinMode(LED_BUILTIN, OUTPUT);
  digitalWrite(LED_BUILTIN, LOW);

  s0.attach(A0);
  s1.attach(A1);
  s2.attach(A2); 

}
void loop(){
 //Position 1
  s0.write(100);
  s1.write(170);
  s2.write(100);
  delay(5000);



  
 //Position 2
  s0.write(75);
  s1.write(180);
  s2.write(10);
  delay(5000);


   //Position 3
  s0.write(125);
  s1.write(180);
  s2.write(10);
  delay(5000);


   //Position 4
  s0.write(125);
  s1.write(0);
  s2.write(0);
  delay(5000);


    //postion 5
  s0.write(75);
  s1.write(0);
  s2.write(0);
  delay(5000);

}




  
  

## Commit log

2019-11-14 Updated pitch link
2019-12-05 3D Printed Models
    [1-Handle.STL, 2-JointTwo.STL, 3-JointThree.STL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]
2019-12-05 3D Models
    [1-Handle.STL, 2-JointTwo.STL, 3-JointThree.STL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]
2019-12-05 .STL 3D Models
    [1-Handle.STL, 2-JointTwo.STL, 3-JointThree.STL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]
2019-12-05 Updated 3D model Titles
    [2-JointOne.STL, 3-JointTwo.STL]
